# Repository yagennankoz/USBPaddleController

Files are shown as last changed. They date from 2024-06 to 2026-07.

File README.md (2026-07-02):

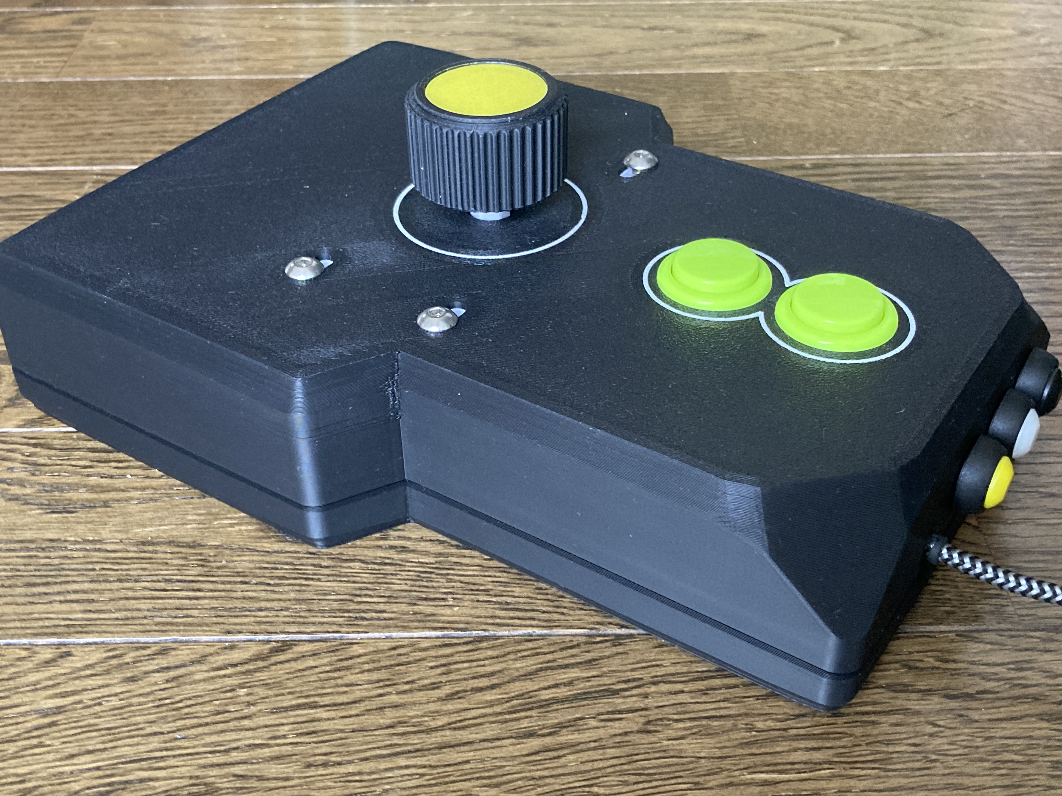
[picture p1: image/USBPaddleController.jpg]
USBパドルコントローラ外観
<br>
RaspberryPi pico版<br>
<br>
USBパドルコントローラ外観<br>
RP2040-Zero版<br>
<br>
<br>

# USBPaddleController

raspberrypi picoを使用したUSBパドルコントローラです<br>
USBマウスとして動作しますので、それらの入力を受け付けるソフトであれば大抵動くんじゃないかと思います *(USBゲームパッドモードも追加しました)*<br>
X/Y軸の切り替えと速度変更にも対応しています<br>

## パドル本体について
パドルユニット部は、ういよめん氏作のパドルコントローラを使用します<br>
https://www.thingiverse.com/thing:5404242
<br>
ういよめん氏のBOOTHで購入する、自分で3Dプリントする等の手段で別途ご用意ください<br>
https://uiyomengames.booth.pm/items/3914858
<br>
当方未確認ですが、ういよめん氏のパドルコントローラのネジ位置はアーケード版アルカノイド用のパドルと寸法が合わせてあるそうなので、そちらも使えるかもしれません<br>

## パドル以外のハードウェア
hardwareフォルダにはパドルユニットに組み付けるセンサー基板とpicoを載せるメイン基板の回路図とガーバーを入れておきました<br>
ガーバーのzipファイルをそのままJLCPCBに送ることで基板を発注できます(たぶん数百円)<br>
組立時の注意としては、センサー基板は位置がずれると正常に動きを検知できなくなるようです<br>
パドルユニットの「ギア4」の中心が二つのセンサーの中心付近にくるようにしてください<br>

## 使用部品

### メイン基板 (RaspberryPi pico版)
| 部品 | 型番 | 個数 | 備考 |
| --- | --- | --- | --- |
| マイコン | RaspberryPi pico | 1 | |
| ダイオード | 1SS178 | 2 | メイン基板 D1,D2 |
| XHコネクタ ベース付ポスト トップ型 2P | B2B-XH-A(LF)(SN) | 5 | メイン基板J2-J6 |
| XHコネクタ ベース付ポスト トップ型 4P | B4B-XH-A(LF)(SN) | 1 | メイン基板J1 |

<br>
<br>

### メイン基板 (RP2040-Zero版)
| 部品 | 型番 | 個数 | 備考 |
| --- | --- | --- | --- |
| マイコン | RP2040-Zero | 1 | |
| ダイオード | 1SS178 | 2 | メイン基板 D1,D2 |
| XHコネクタ ベース付ポスト トップ型 2P | B2B-XH-A(LF)(SN) | 5 | メイン基板J2-J6 |
| XHコネクタ ベース付ポスト トップ型 4P | B4B-XH-A(LF)(SN) | 1 | メイン基板J1 |

<br>
<br>

### センサー基板 (センサー基板はpico/RS2040-Zero共通です)
| 部品 | 型番 | 個数 | 備考 |
| --- | --- | --- | --- |
| インバータ | 74HC14<br>(U74HC14L-D14-T) | 1 | センサー基板 |
| 透過型フォトインタラプタ | SG206 | 2 | センサー基板 U2,U3 他のパーツの裏側に付きます |
| カーボン抵抗 | 180Ω | 2 | センサー基板 R1,R2 |
| カーボン抵抗 | 2.2kΩ | 2 | センサー基板 R3,R4 |
| XHコネクタ ベース付ポスト トップ型 4P | B4B-XH-A(LF)(SN) | 1 | センサー基板J1|

<br>
<br>

### 配線 (pico/RS2040-Zero共通)
| 部品 | 型番 | 個数 | 備考 |
| --- | --- | --- | --- |
| XHコネクタ ハウジング 2P | XHP-2 | 5 | |
| XHコネクタ ハウジング 4P | XHP-4 | 2 | |
| XHコネクター ハウジング用コンタクト | SXH-001T-P0.6 | 18 |  |
| 配線 | | 適量 | 最低4色は揃えるのが良いでしょう |

<br>
<br>

### ケース(RaspberryPi pico版)
| 部品 | 型番 | 個数 | 備考 |
| --- | --- | --- | --- |
| 24φネジ式押しボタン | PS-14-DN | 2 | |
| ネジ径12Φ押しボタン |  | 3 | |
| M3 インサートナット |  | 6 | ケース上部パーツの穴に入れる |
| M3 5mm ビス |  | 4 | |
| M5 ナット |  | 4 | パドルユニットをケースに組み付けるのに使用 |
| M5 15mm ビス |  | 4 | パドルユニットをケースに組み付けるのに使用 |
| M3 6mm タッピングビス |  | 6 | ケースにメイン基板を固定するのに4個<br>パドルユニットにセンサー基板を固定するのに2個 |

<br>
<br>

### ケース(RS2040-Zero版)
| 部品 | 型番 | 個数 | 備考 |
| --- | --- | --- | --- |
| 24φネジ式押しボタン | PS-14-DN | 3 | |
| サービススイッチ(DS-412) |  | 2 | |
| M3 インサートナット |  | 7 | ケース上部パーツの穴に入れる |
| M3 5mm ビス |  | 4 | |
| M5 ナット |  | 4 | パドルユニットをケースに組み付けるのに使用 |
| M5 15mm ビス |  | 4 | パドルユニットをケースに組み付けるのに使用 |
| M3 6mm タッピングビス |  | 3 | ケースにメイン基板を固定するのに3個<br>パドルユニットにセンサー基板を固定するのに2個<br> |

<br>
<br>

### パームレスト(RS2040-Zeroケース用追加装備)
| 部品 | 型番 | 個数 | 備考 |
| --- | --- | --- | --- |
| M3 8mm ビス |  | 2 | |

<br>
<br>

### メイン基板上のコネクタとスイッチの対応
| picoコネクタ# | RP2040-Zeroコネクタ# | スイッチ# | 機能 |
| --- | --- | --- | --- |
| J2 | J2 | SW1 | 左ボタン |
| J3 | J3 | SW2 | 右ボタン |
| J4 | J5 | SW3 | 速度切り替えボタン |
| J5 | J6 | SW4 | X/Y軸切り替えボタン |
| J6 | J4 | SW5 | センターボタン |

<br>
<br>
<br>

## ファームウェアの書込み

### RaspberryPi picoの場合
picoのBOOTSELを押しながらUSBケーブルを接続するとエクスプローラーが起ち上がり、picoのフォルダが表示されます(winの場合）<br>
そこにUSBPaddleController_pico.uf2をコピーしてください<br>
ファームウェアの更新が完了するとpicoが再起動します<br>

### RP2040-Zeroの場合
PCに接続した状態でZeroのBOOTを押しながらRESETを押下するとエクスプローラーが起ち上がり、Zeroのフォルダが表示されます(winの場合）<br>
そこにUSBPaddleController_rp2040_zero.uf2をコピーしてください<br>
ファームウェアの更新が完了するとZeroが再起動します<br>
<br>
<br>
<br>

## ボタンの機能について
### 速度切り替えボタン
SW3は速度切り替えボタンです<br>
パドルの反応速度を4段階で切り替えることが可能です<br>
押下するごとに高速から順に低速に切り替わり、最低速の次は高速に戻ります<br>
切り替え後の速度はLEDのフラッシュで通知されます(最高速=1回...最低速=4回)<br>

### X/Y軸切り替えボタン
SW4はX/Y軸切り替えボタンです<br>
押下するごとにマウスの移動方向が切り替わります<br>
X軸移動のみでは「メタルオレンジEX」のメニュー操作ができなかったので追加しました<br>
*軸切り替えボタンと右または左ボタン同時押しのセンタークリックは廃止しました*<br>

### 連射モード
**速度切替ボタンを押しながら**左右センターいずれかのボタンを押すと連射モードのON/OFF切り替えが行われます<br>
連射モードONになっているボタンを押下している間、連射します<br>
連射速度は秒間10発程度の固定です<br>

---

### ゲームパッドモード(ポールポジションモード)
**X/Y軸切り替えボタン**と**速度切り替えボタン**を同時押しすると、USBマウスモードとUSBゲームパッドモードが交互に切り替わります<br>
ゲームパッドモードに切り替わった時、LEDが10秒間点滅します(RP2040-Zetoでは緑色点滅)<br>
マウスモードに切り替わった時、LEDが10秒間点灯します(RP2040-Zetoでは赤色点灯)<br>
USBゲームパットモードではボタンの機能が以下のようになります<br>

| マウス操作 | パッド操作 |
| --- | --- |
| 回転 | 左スティック |
| 左 | R2<br>3秒以上長押しした後に離すと、L2が自動で0.9秒間連打されます(オートブレーキ)<br>L2連打中に再度ボタン押下で連打がキャンセルされます<br>オートブレーキ作動中はLEDが点滅します |
| 右 | ×/□のトグル動作 |
| センター | △ |
| 速度切り替え | PS |

速度切り替え/連射は無効化されます<br>
その他のボタン機能はUSBマウスモードと同様に機能します<br>
PS5との接続はFGC2を介してどうにかなるかもしれません<br>

---

### 設定の保存
マウス/ゲームパッドのモードと各設定値は設定変更のタイミングで保存され、再起動時は設定内容を復元します<br>
設定値はマウス/ゲームパッドのモード毎に保存されます<br>
<br>
<br>

---

### ケースについて
パドルコントローラのケースはサイズ違いのものを用意しました<br>
小さい方は20cmX20cmのヒートベッドで出力可能ですが、2ボタン仕様であり手の置き場もないため若干操作しづらくなっています<br>
大きい方はケースの締め付けにインサートナットを使用しますので別途ご用意ください<br>
自作されたり、アーケード機のコントロールボックス等に入れるのも良いと思います<br>
<br>

---

### 組み立て手順
#### パドルユニットの作成
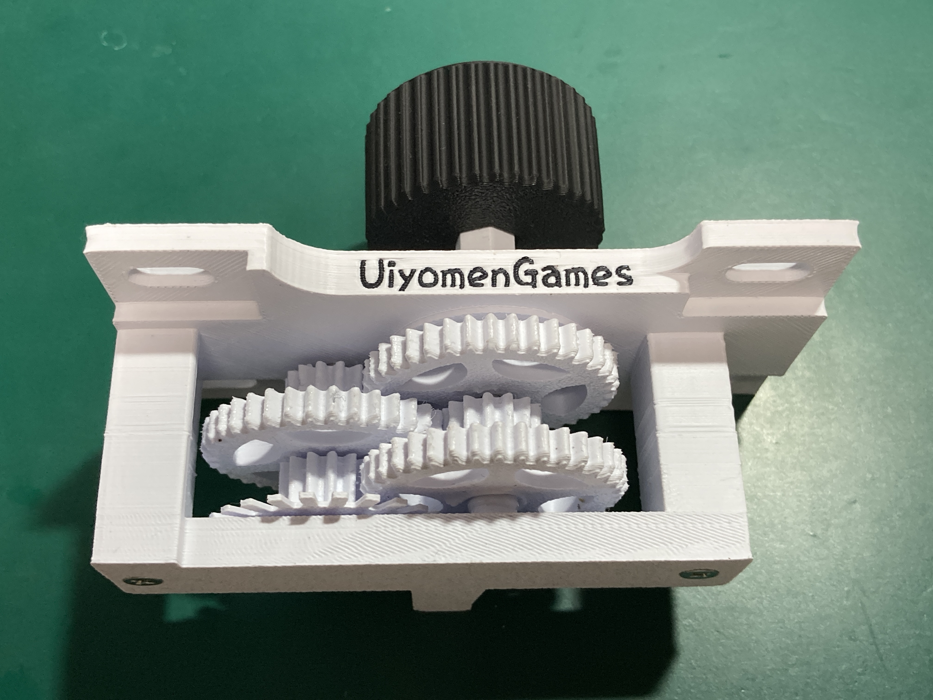
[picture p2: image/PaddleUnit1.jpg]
パドルユニット
<br>
<br>

- 公開されているデータをもとに3Dプリント等を行ってください<br>
<br>

***
#### 基板の作成
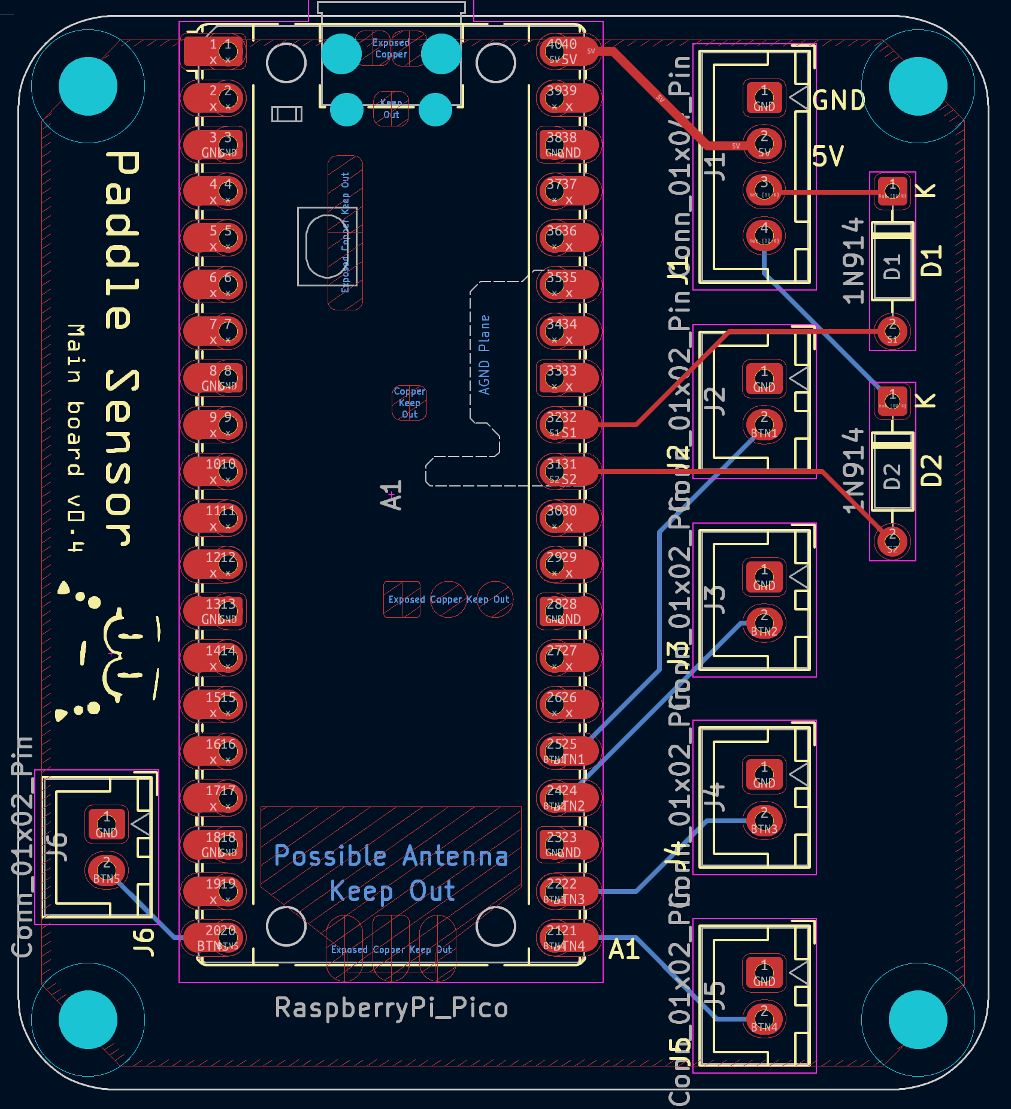
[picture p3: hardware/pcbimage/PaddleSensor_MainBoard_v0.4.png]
メイン基板 pico用
<br>
メイン基板 RaspberryPi pico用<br>
<br>
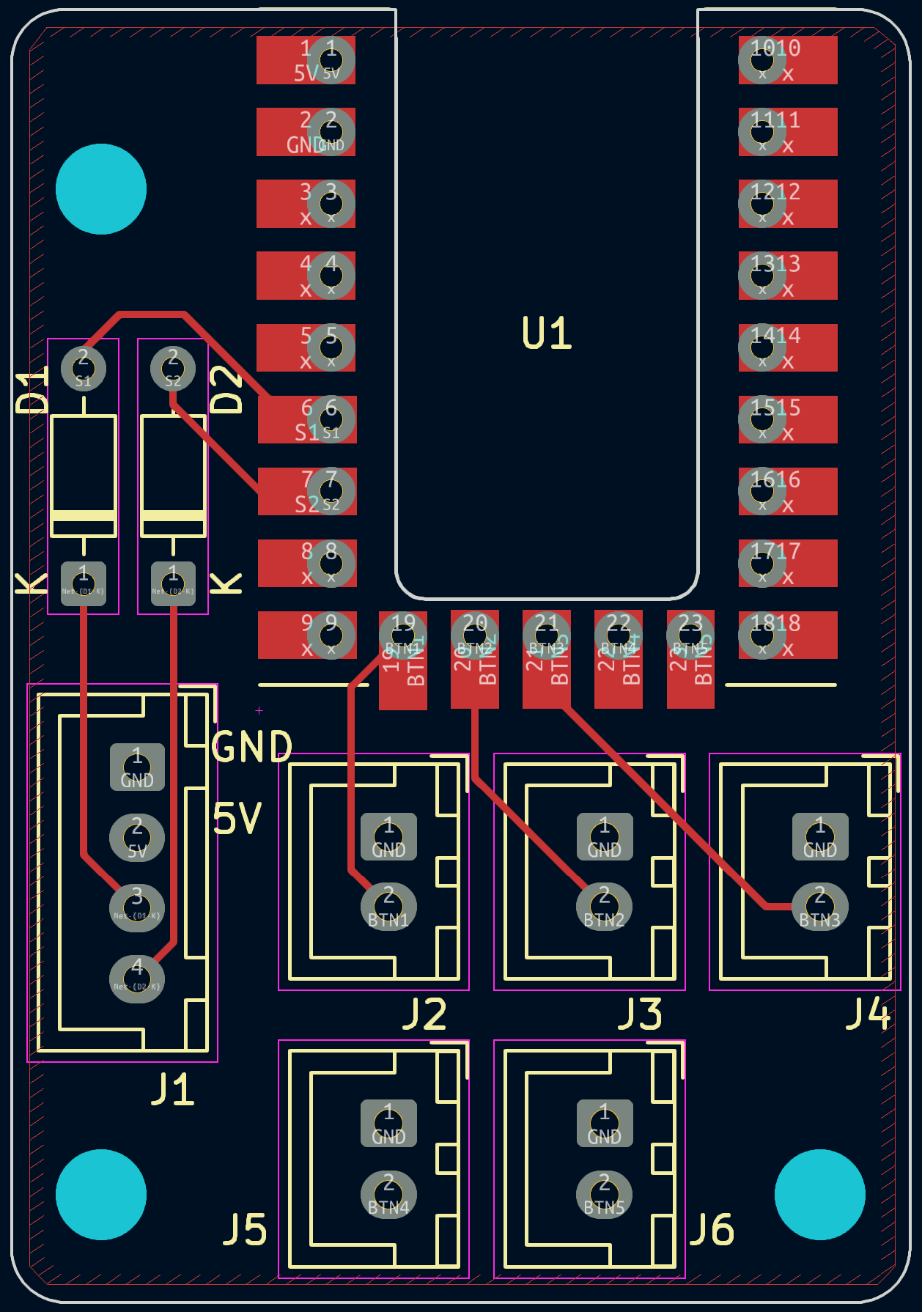
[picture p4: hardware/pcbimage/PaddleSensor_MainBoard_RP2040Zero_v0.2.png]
メイン基板 RP2040-Zero用
<br>
メイン基板 RP2040-Zero用<br>
<br>
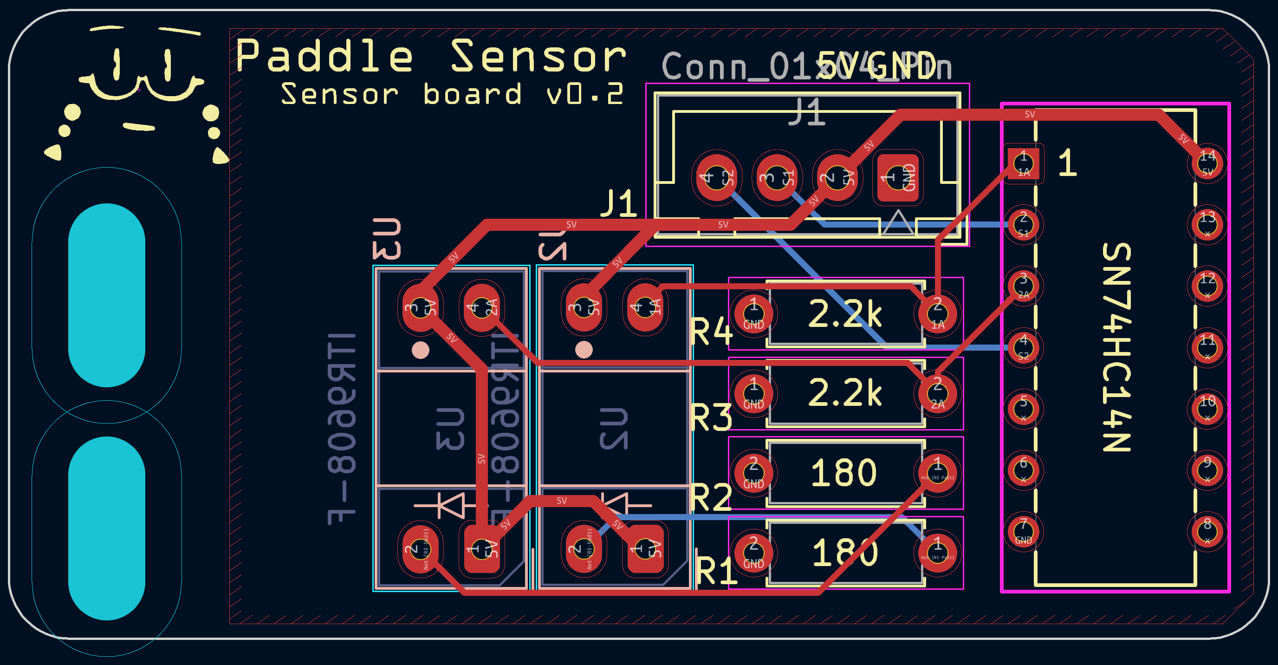
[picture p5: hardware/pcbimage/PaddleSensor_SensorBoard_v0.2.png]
センサー基板
<br>
センサー基板<br>
<br>
<br>

- 基板イメージと使用部品表を参考に部品を半田付けしてください<br>
- メイン基板は使用するマイコンによってRaspberryPi pico用かRP2040-Zero用のどちらかを使用してください<br>
- センサー基板はどちらのマイコンを使う場合でも共通です<br>
- メイン基板へのRaspberryPi picoの取り付けはピンヘッダ／ソケットを使用することを前提としています<br>
- メイン基板へのRP2040-Zeroの取り付けはピンヘッダを使用せず直接はんだ付けすることを前提としています<br>
- センサー基板のフォトインタラプタはその他の部品の裏側の面に実装します<br>
<br>

***
#### パドルユニットにセンサー基板を取り付け
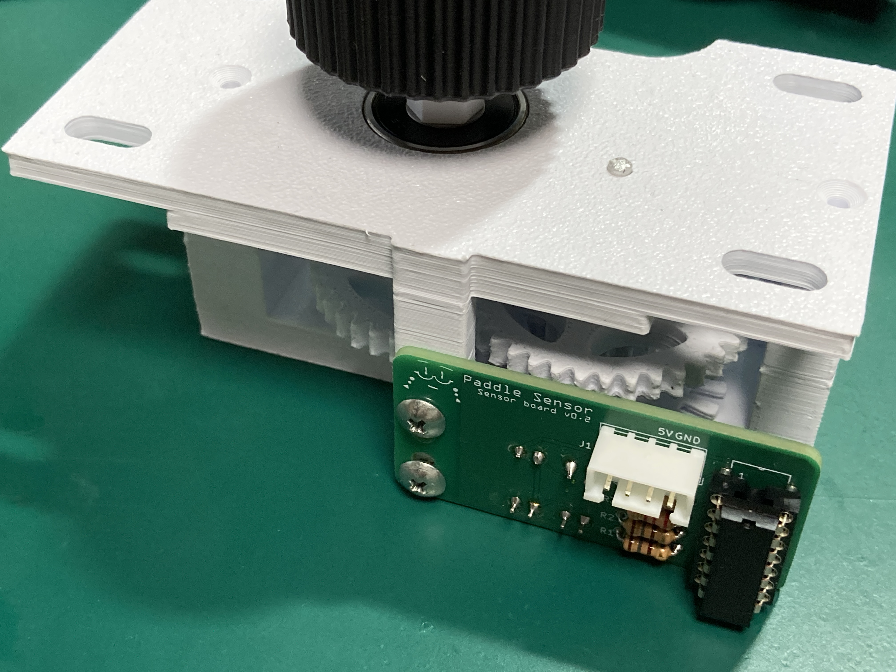
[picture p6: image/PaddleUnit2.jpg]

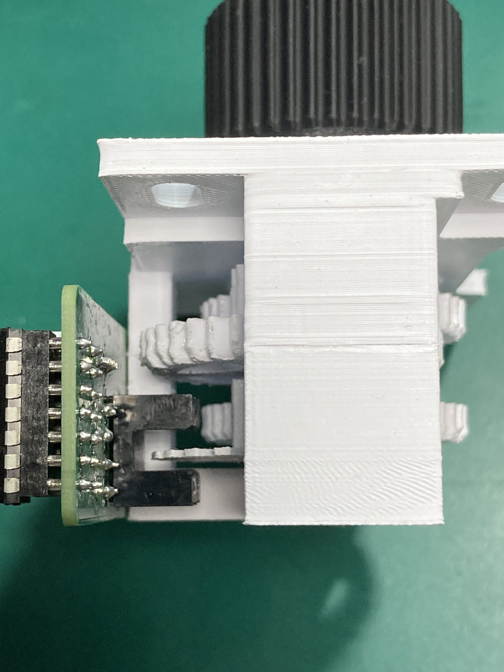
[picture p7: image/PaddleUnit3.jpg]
<br>
<br>

- パドルユニットにセンサー基板を取り付けます<br>
- フォトインタラプタとパドルユニットの円盤が接触しないようにしてください<br>
<br>

***
#### ケース(上)にインサートナットの埋め込み
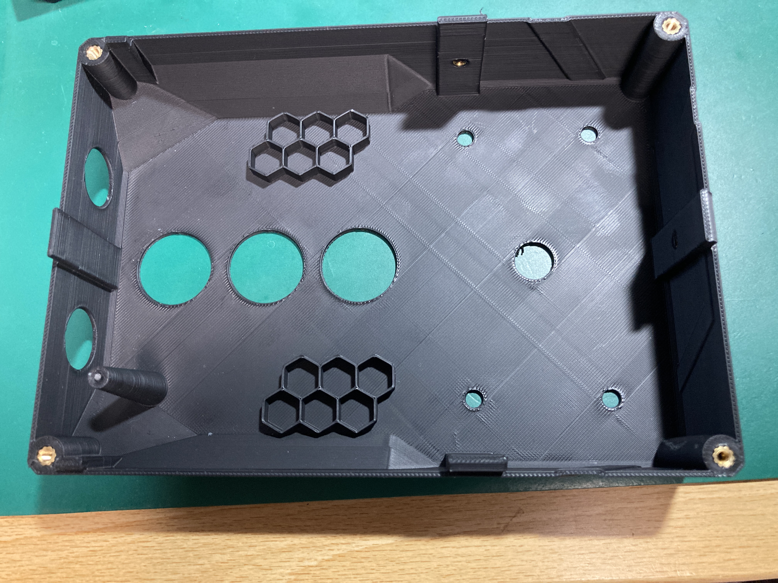
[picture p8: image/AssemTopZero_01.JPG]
<br>

- ケース(上)の底面の穴にM3用のインサートナットを埋め込みます
- pico用は6か所、RP2040-Zero用は4か所です

<br>
<br>
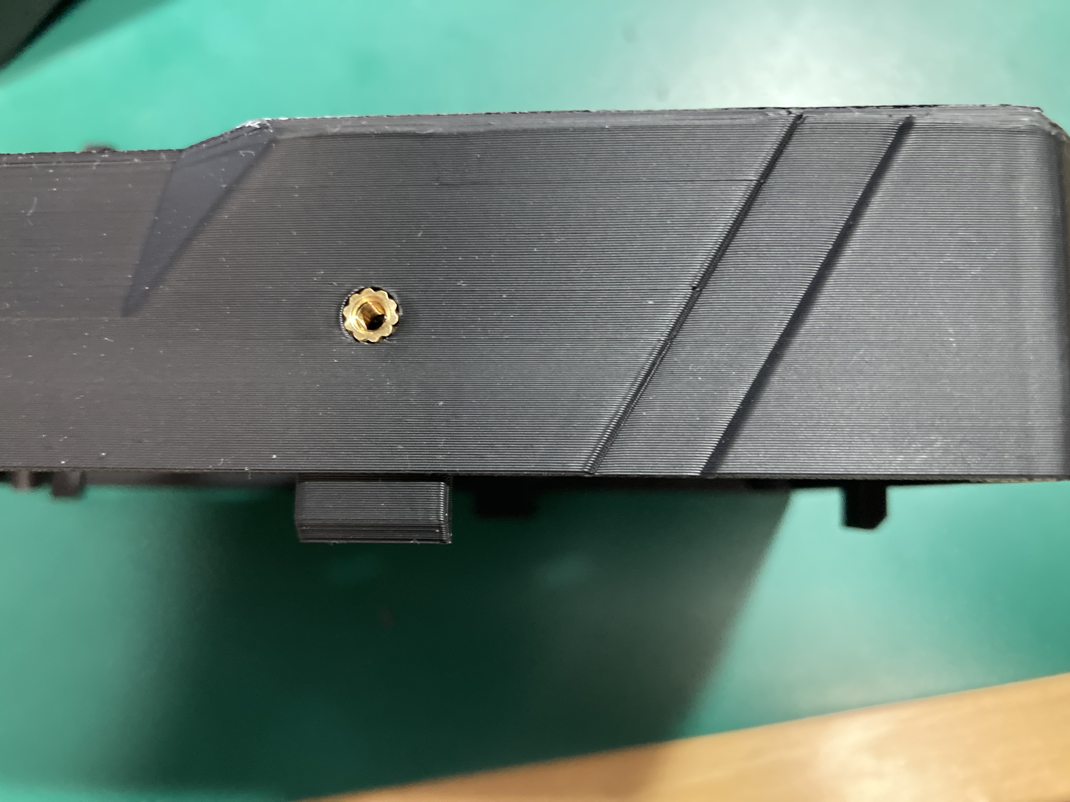
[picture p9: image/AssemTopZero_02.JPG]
<br>

- RP2040-Zero用は側面の3か所の穴にもM3用のインサートナットを埋め込みます

<br>
<br>

***
#### ケース(上)に透明フィラメントの埋め込み(RP2040-Zeroのみ)
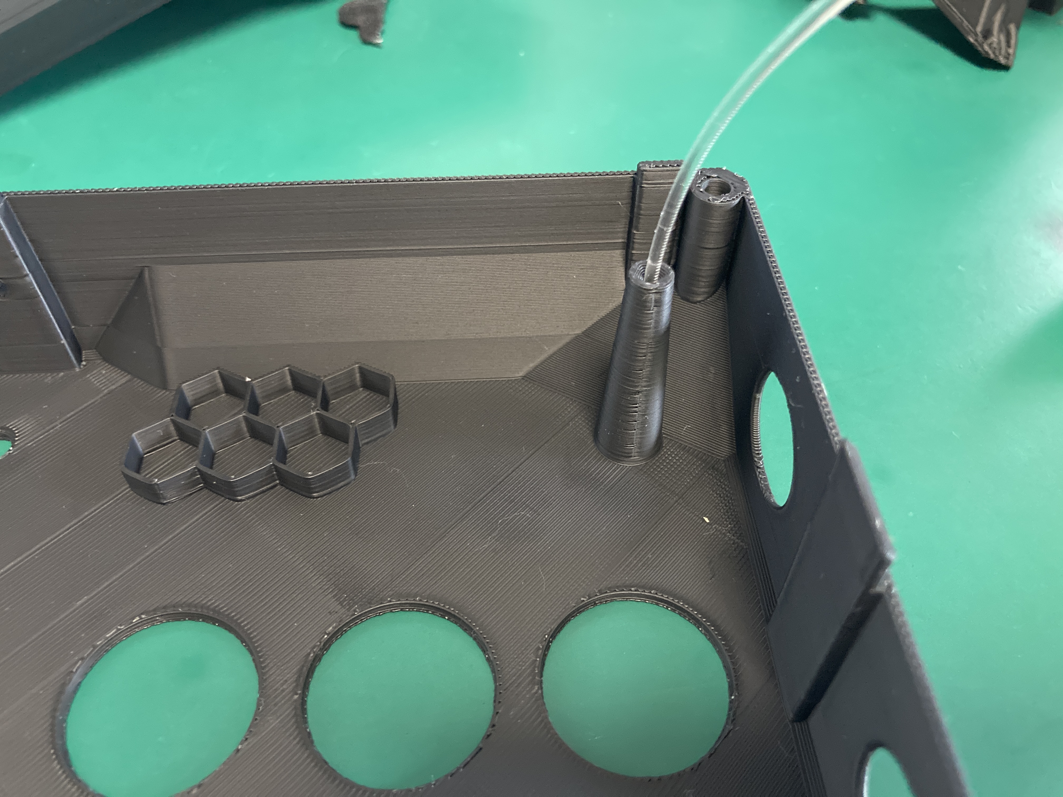
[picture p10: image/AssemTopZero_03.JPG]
<br>
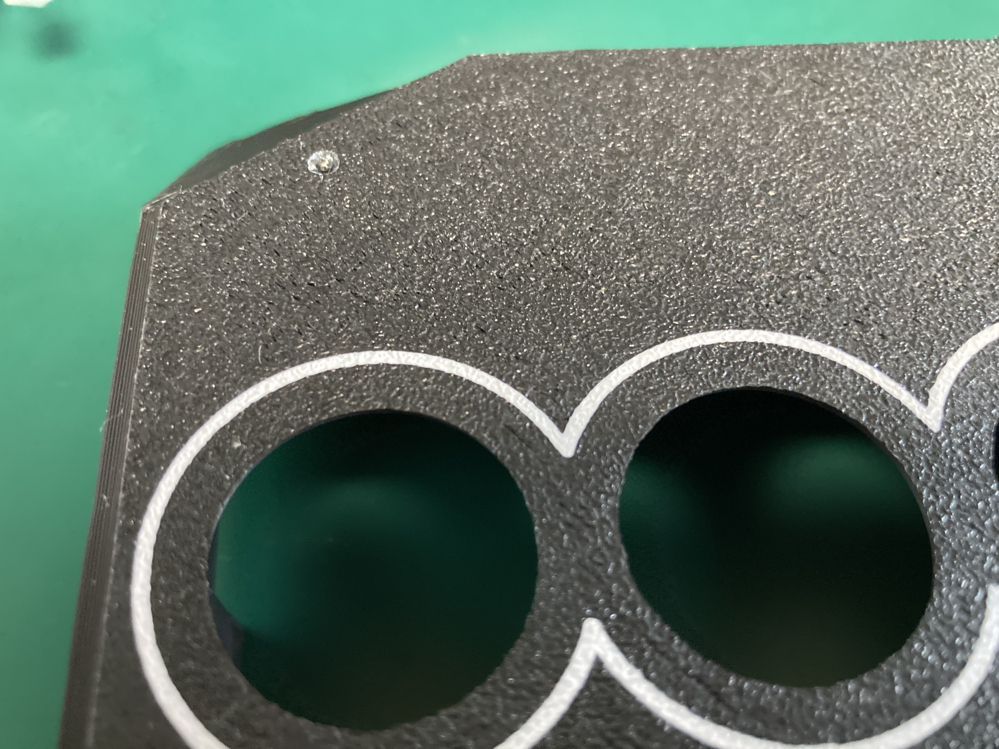
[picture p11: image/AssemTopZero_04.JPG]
<br>
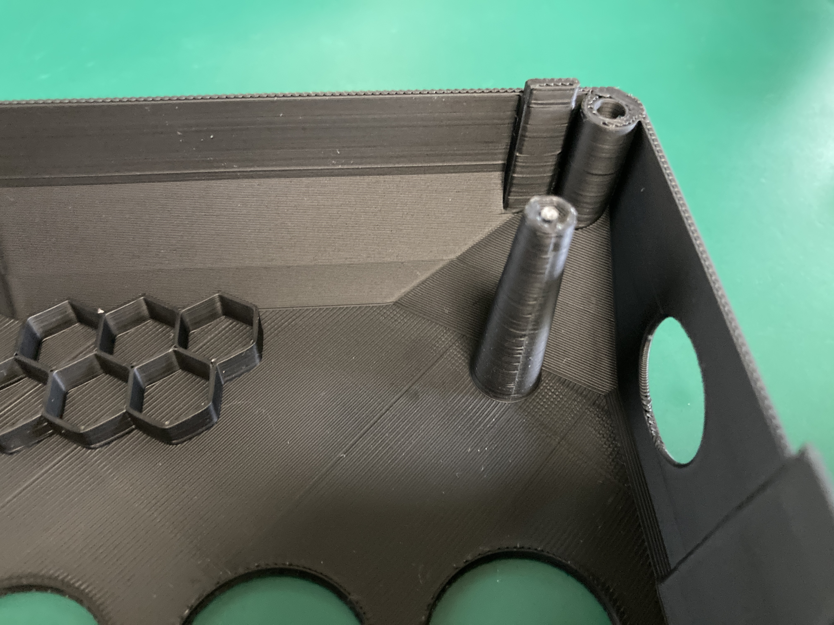
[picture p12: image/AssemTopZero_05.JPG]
<br>

- 2mm穴に透明フィラメントを埋め込みます
- 両端がケースの面とツライチになるようにカットしてください
- 透明フィラメントが無い場合はスキップしても問題ありません

<br>
<br>

***
#### ケース(上)にパドルユニットとスイッチを取り付け
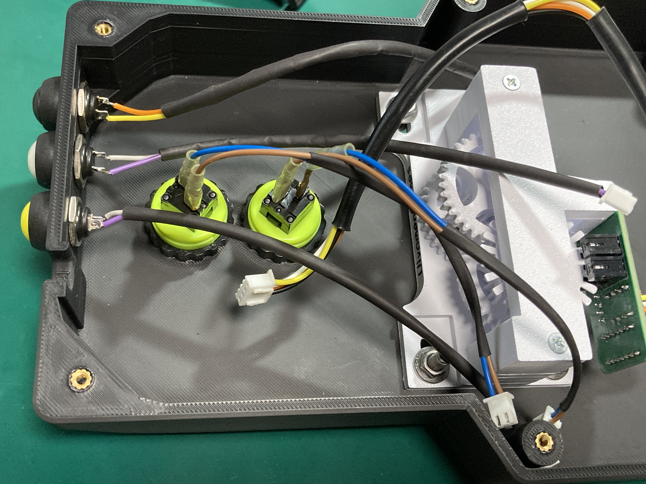
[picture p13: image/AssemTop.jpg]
picoケース(上)
<br>
<br>
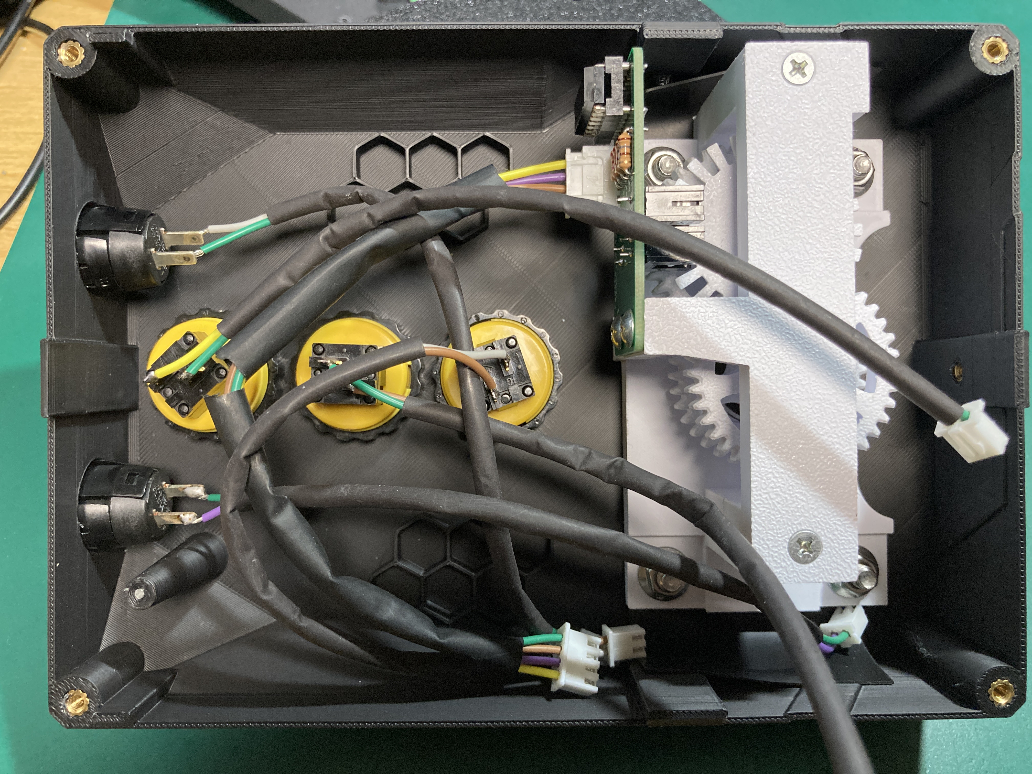
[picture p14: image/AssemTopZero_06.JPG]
Zeroケース(上)
<br>
<br>

- ケース(上)にパドルユニットとボタンを取り付けます
- pico用とRP2040-Zero用ではパドルユニットが異なっています

<br>
<br>

***
#### ケース(下)にメイン基板を取り付け
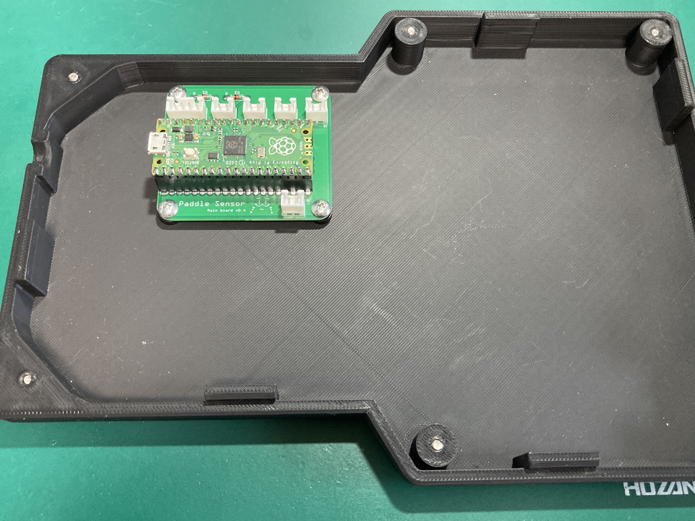
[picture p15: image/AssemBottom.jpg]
ケース(下)
<br>
<br>

- ケース(下)にメイン基板を取り付けます<br>

***
#### メイン基板と接続
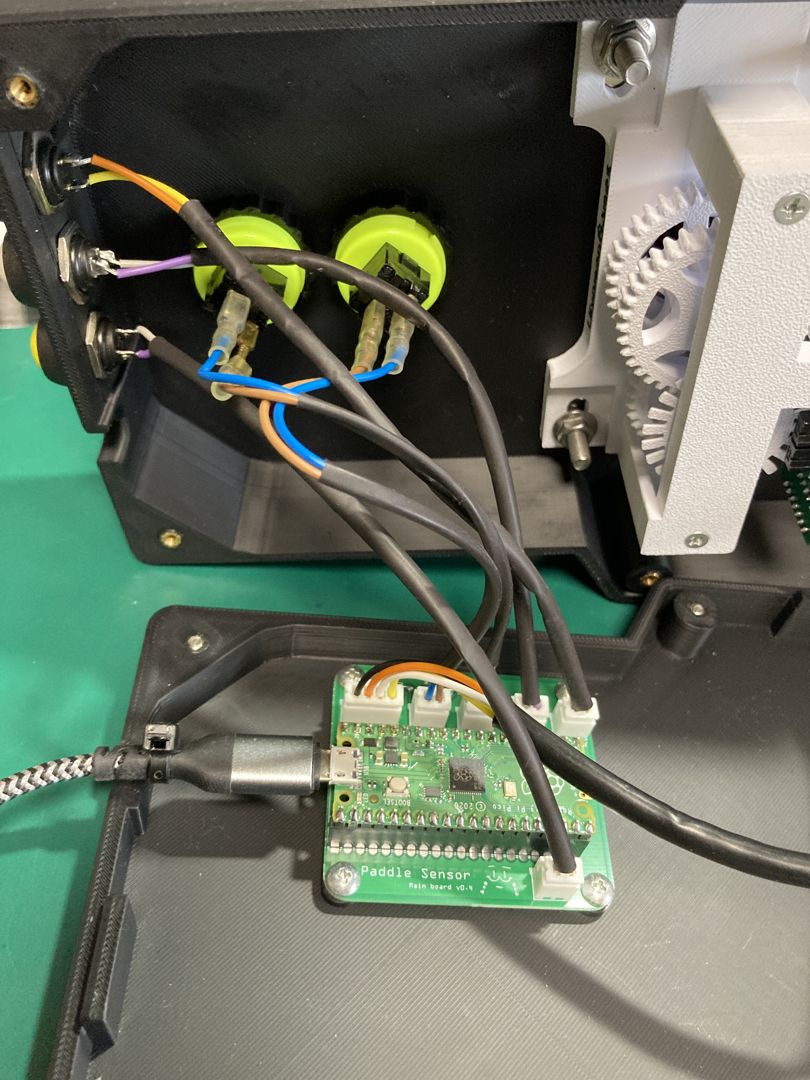
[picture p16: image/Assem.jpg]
配線
<br>
<br>

- メイン基板とセンサー基板、各スイッチを接続します<br>
- スイッチ類はすべて同じコネクタ形状ですので、配置はお好みで組み替えてください<br>

***
#### 完成
完成<br>
<br>
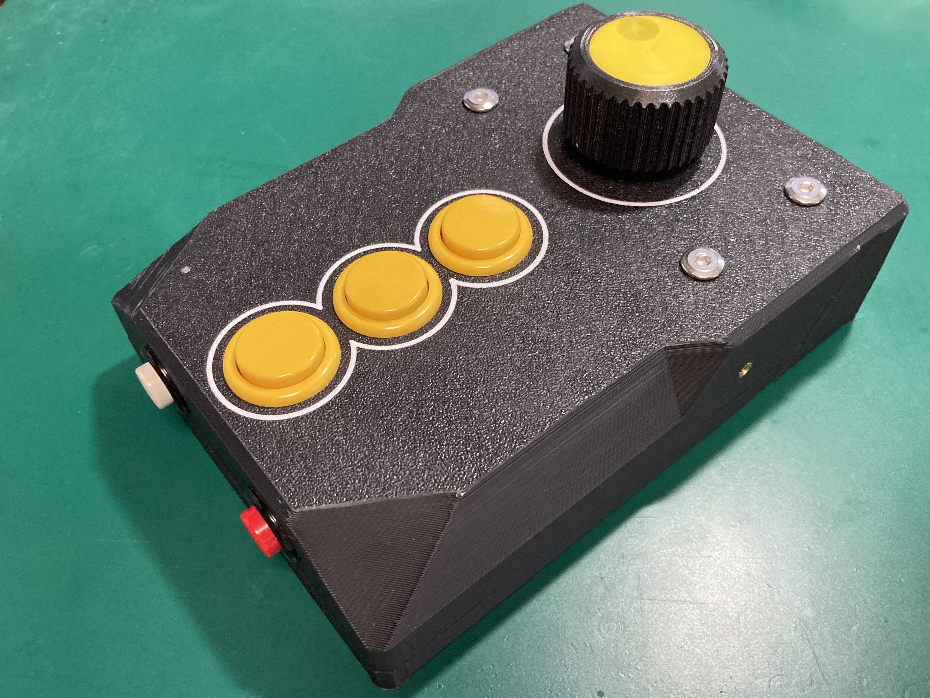
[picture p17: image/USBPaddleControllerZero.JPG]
<br>
<br>

- ケースを閉じて完成です　お疲れさまでした<br>
<br>
<br>

---
### RP2040-Zero用追加装備
RP2040-Zero用ケースは側面に3か所のナットが埋め込まれています<br>
ここに追加装備を装着することが可能です<br>
<br>

#### パームレスト
RP2040-Zero用ケースはコンパクトになった反面、手を置くスペースがなくなっているので、外付けのパームレストを作成しました<br>
取り付け位置を替えることで右手／左手のどちらにも対応可能です<br>
またパームレスト天面にM3ビス用の穴を5個あけていますので、上部にさらに装備追加可能です<br>
<br>
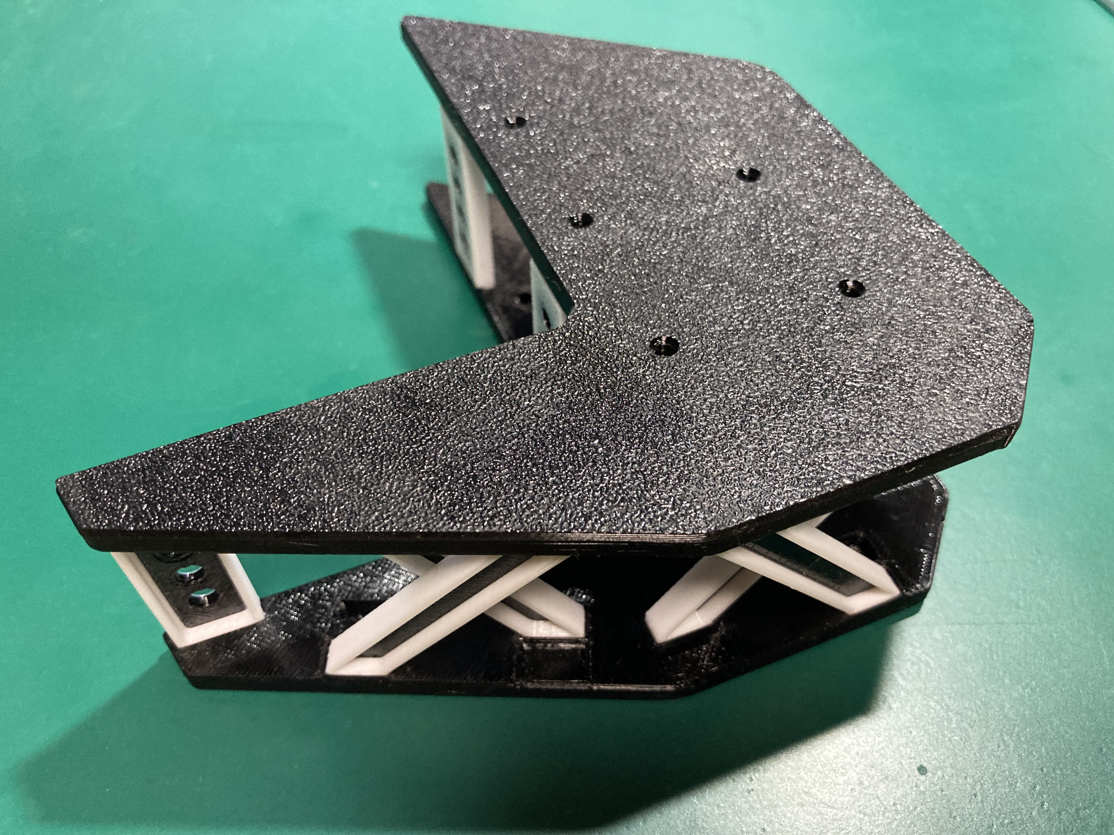
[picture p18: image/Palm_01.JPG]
パームレスト
<br>
パームレスト<br>
パームレスト<br>

<br>
<br>

#### パームレスト組立手順
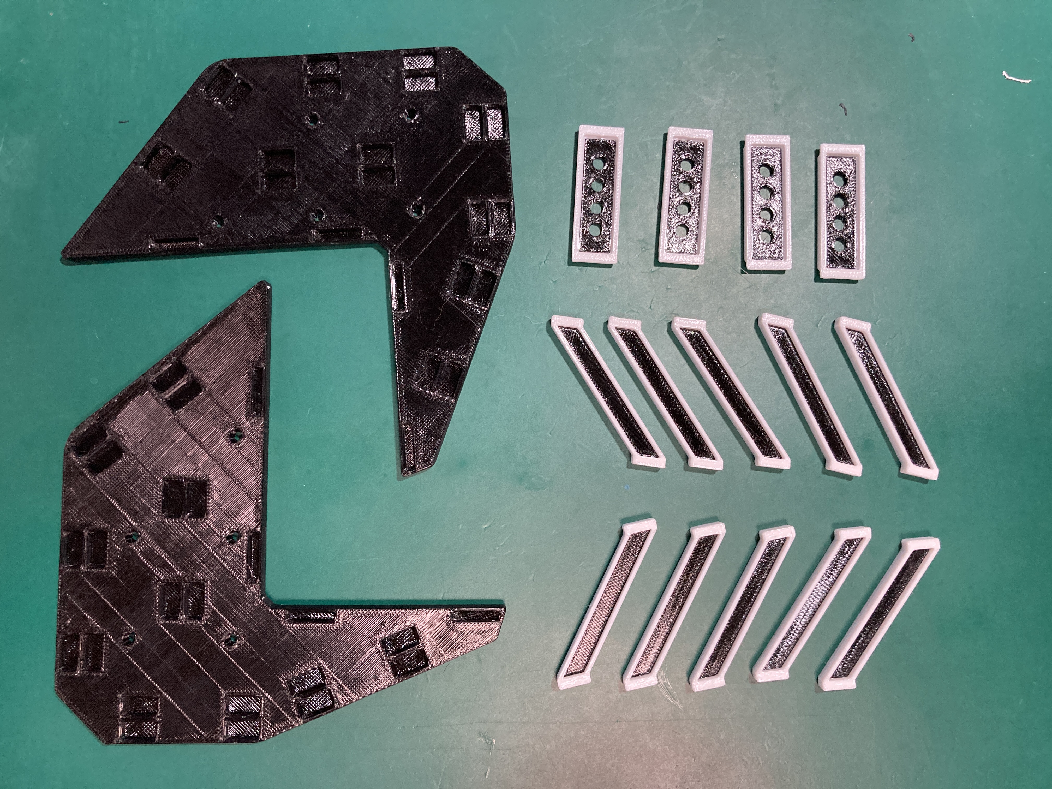
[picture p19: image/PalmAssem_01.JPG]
パームレスト部品
<br>
<br>
- 部品を準備します
- 垂直支柱は4本、斜め支柱は2種類を各5本ずつ出力してください

<br>

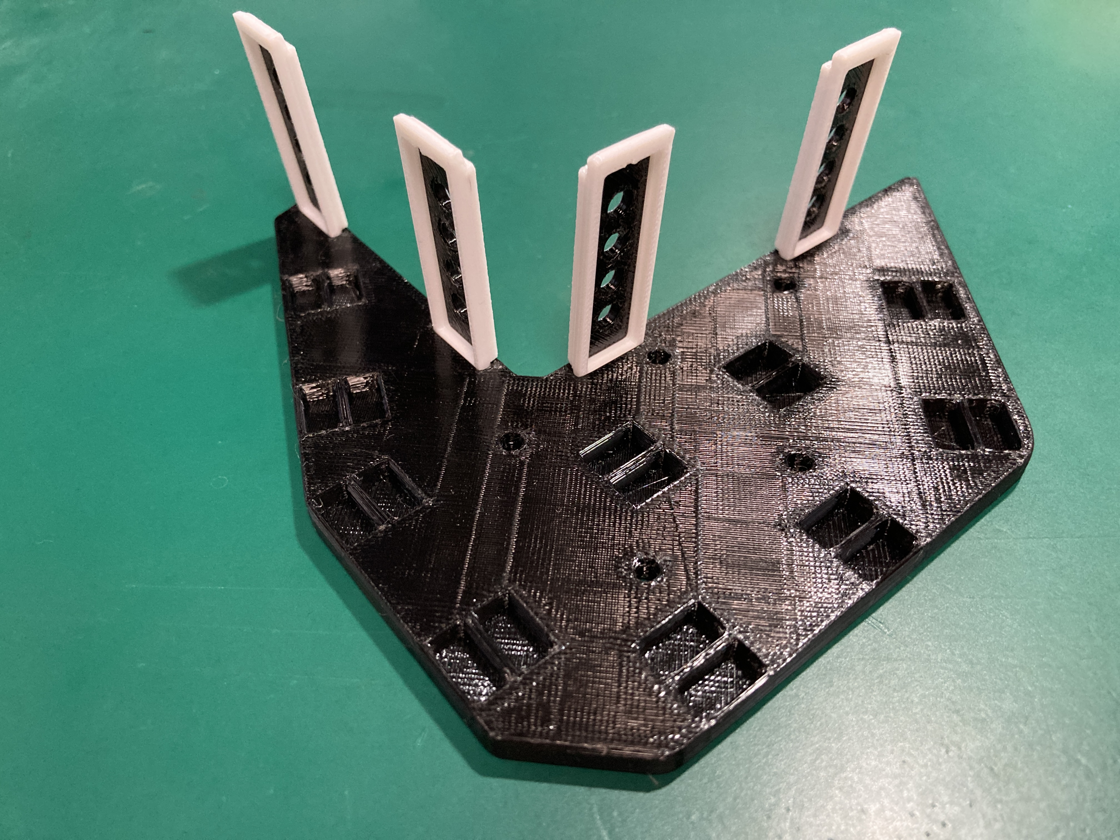
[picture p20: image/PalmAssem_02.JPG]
<br>
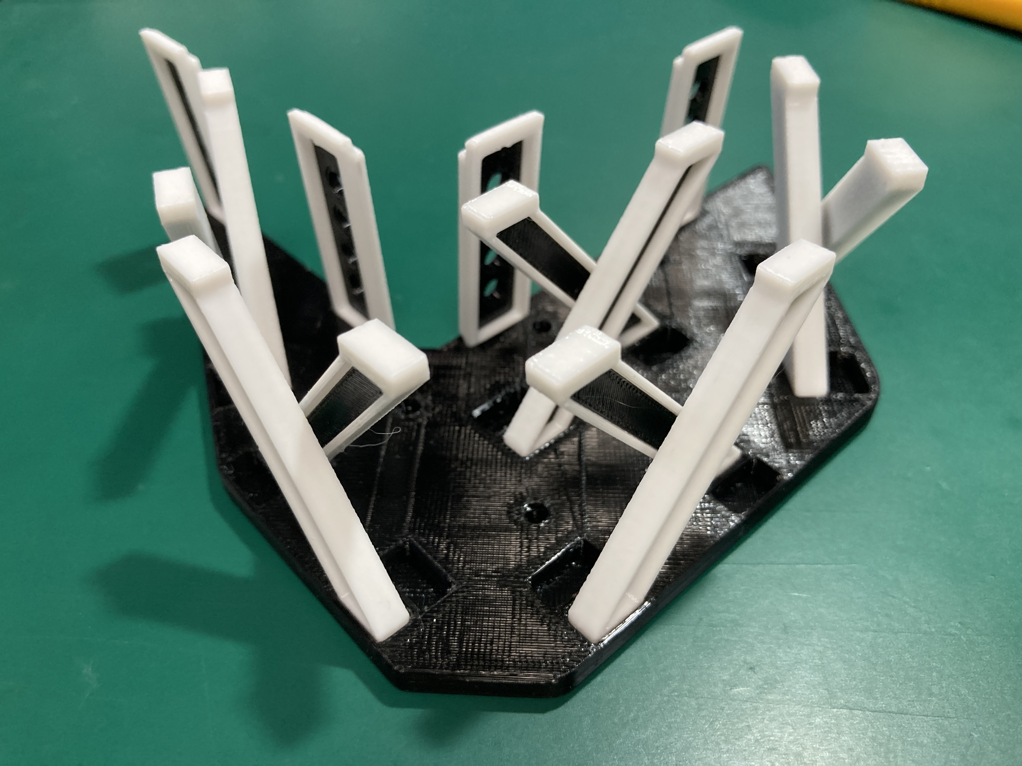
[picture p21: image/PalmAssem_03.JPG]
<br>
<br>
- 片方のプレートに支柱を立てます
- 垂直支柱は窪みがある面を斜め支柱が刺さる穴の方に向けてください
- 斜め支柱の向きや本数はお好みでどうぞ

<br>

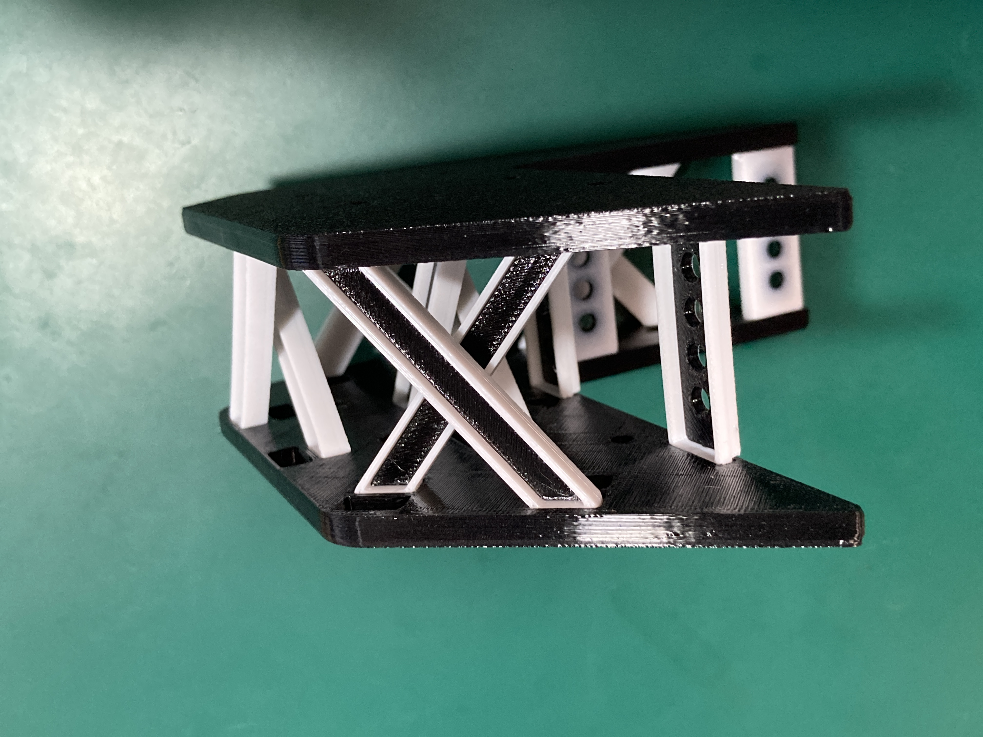
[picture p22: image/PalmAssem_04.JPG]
<br>
<br>
- もう片方のプレートに立てている支柱を差し込んで完成です

<br>
<br>

---
### テスト環境
以下のテスト環境で動作確認を行っています<br>
- X68000 Z<br>
- PlayStation 5 (ゲームパッドモードはBrook FGC2を使用)<br>
- Windows11<br>
<br>

---

### 参考サイト
- ういよめん氏　Arkanoid Paddle (spinner) controller Rotary encoder<br>
https://www.thingiverse.com/thing:5404242

- わいくん氏　ゲーム基板用センサー図鑑<br>
https://www.ykuns-mechanical-club.com/game%20sensor.html

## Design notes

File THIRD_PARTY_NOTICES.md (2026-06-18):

# THIRD-PARTY NOTICES

This repository uses third-party software components.

Generated: 2026-06-18

## Scope

- This file documents licenses for components resolved by PlatformIO for environment `pico`.
- Actual linked components can vary by platform/core/library versions.
- This file is for notice purposes only and is not legal advice.

## Direct Dependency (declared in platformio.ini)

### Adafruit TinyUSB Library

- Name: Adafruit TinyUSB Library
- Version observed: 2.4.1
- Declared constraint: `adafruit/Adafruit TinyUSB Library@^2.3.1`
- License: MIT
- Upstream: https://github.com/adafruit/Adafruit_TinyUSB_Arduino
- Local evidence:
  - `.pio/libdeps/pico/Adafruit TinyUSB Library/LICENSE`
  - `.pio/libdeps/pico/Adafruit TinyUSB Library/library.properties`

## Dependencies Observed In Build Graph

The following were present in the PlatformIO dependency graph during build:

- Adafruit TinyUSB Library @ 2.4.1
- EEPROM @ 1.0 (framework-provided)
- SPI @ 1.0 (framework-provided)

Framework package in use:

### framework-arduinopico

- Name: Arduino-Pico core package (`framework-arduinopico`)
- Version observed: 1.30601.0+sha.c3a3526
- License file indicates: GNU Lesser General Public License v2.1 (LGPL-2.1)
- Upstream: https://github.com/earlephilhower/arduino-pico
- Local evidence:
  - `C:/Users/hasegawa/.platformio/packages/framework-arduinopico/LICENSE`

## Transitive Dependencies Pulled By Adafruit TinyUSB Library

These were resolved locally as dependencies of Adafruit TinyUSB Library:

### Adafruit SPIFlash

- Version observed: 4.3.4
- License: MIT
- Upstream: https://github.com/adafruit/Adafruit_SPIFlash
- Local evidence:
  - `.pio/libdeps/pico/Adafruit SPIFlash/LICENSE`

### SdFat - Adafruit Fork

- Version observed: 2.2.3
- License: MIT
- Upstream: https://github.com/adafruit/SdFat
- Local evidence:
  - `.pio/libdeps/pico/SdFat - Adafruit Fork/LICENSE.md`
  - `.pio/libdeps/pico/SdFat - Adafruit Fork/library.properties`

## Recommended Distribution Practice

- Keep this notice file with source releases.
- Include each third-party license text when redistributing binaries/source bundles.
- Re-run dependency and license checks when updating PlatformIO platform/core/library versions.

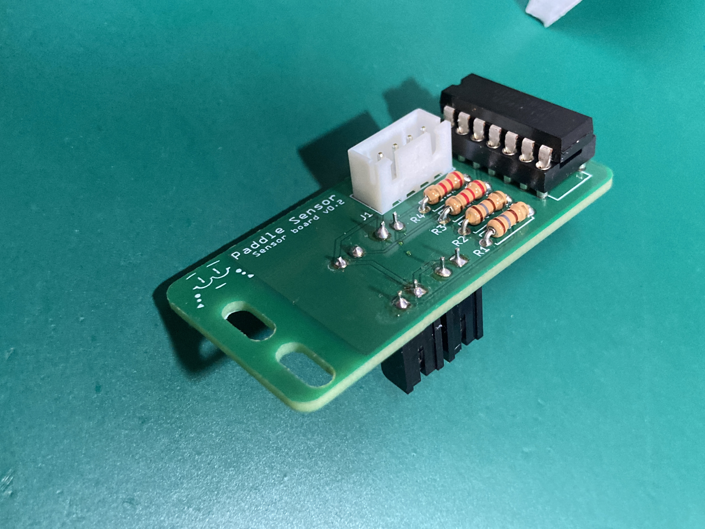
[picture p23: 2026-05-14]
image/SensorBoard.jpg

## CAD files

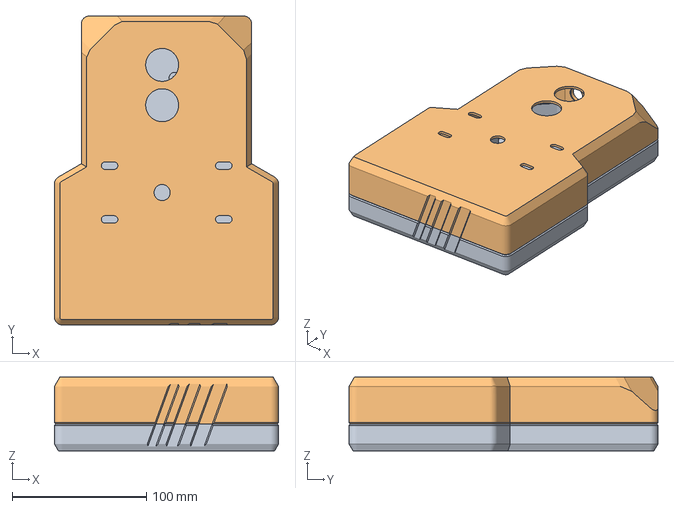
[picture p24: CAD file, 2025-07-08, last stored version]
case/PaddleCaseLarge_4BTN.3mf
166.9 x 230.0 x 55.0 mm
BOTTOM_V2
TOP_V2

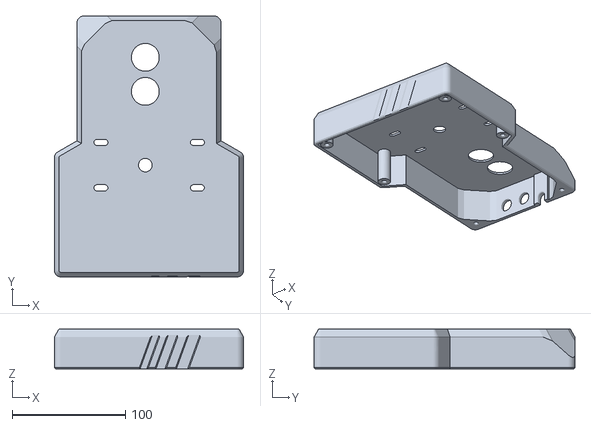
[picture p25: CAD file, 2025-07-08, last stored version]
case/PaddleCaseLarge_TOP_4BTN.stl
166.9 x 230.0 x 35.0

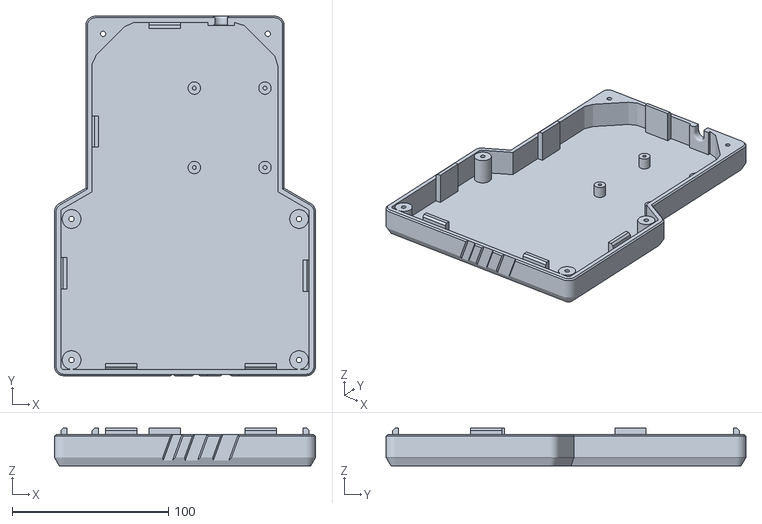
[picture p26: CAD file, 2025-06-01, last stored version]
case/PaddleCaseLarge_BOTTOM.stl
166.9 x 230.0 x 24.0

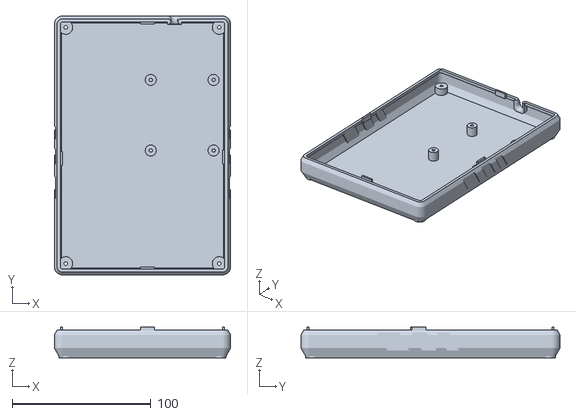
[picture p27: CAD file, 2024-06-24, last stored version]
case/PaddleCase_BOTTOM.stl
126.9 x 186.4 x 22.0

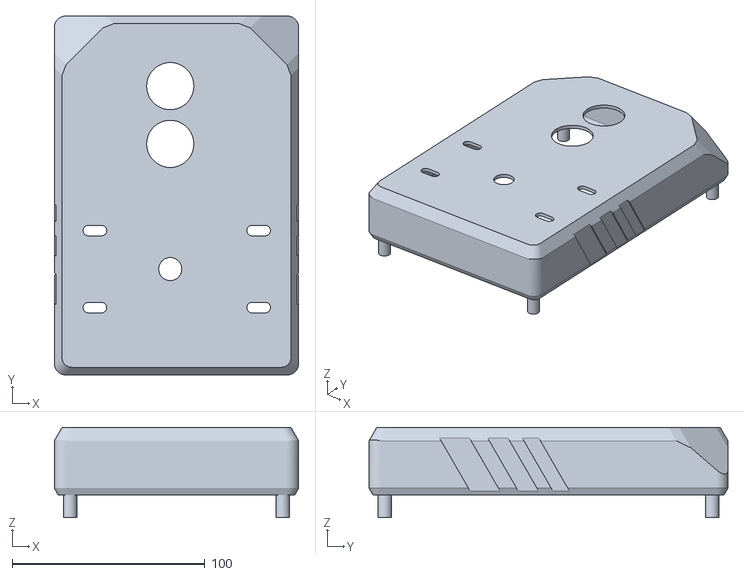
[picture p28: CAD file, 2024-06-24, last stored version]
case/PaddleCase_TOP.stl
126.9 x 186.4 x 46.8

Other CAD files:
case/PaddleCaseLarge.3mf
case/PaddleCaseLarge_TOP.stl

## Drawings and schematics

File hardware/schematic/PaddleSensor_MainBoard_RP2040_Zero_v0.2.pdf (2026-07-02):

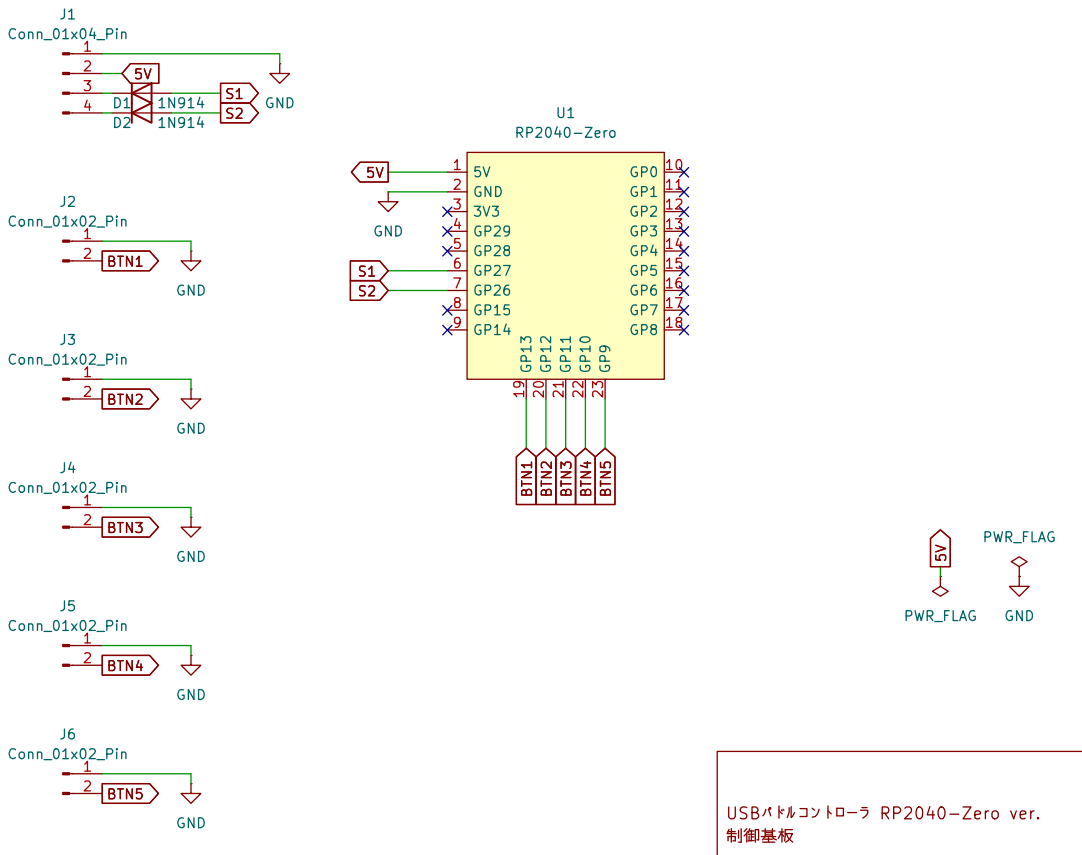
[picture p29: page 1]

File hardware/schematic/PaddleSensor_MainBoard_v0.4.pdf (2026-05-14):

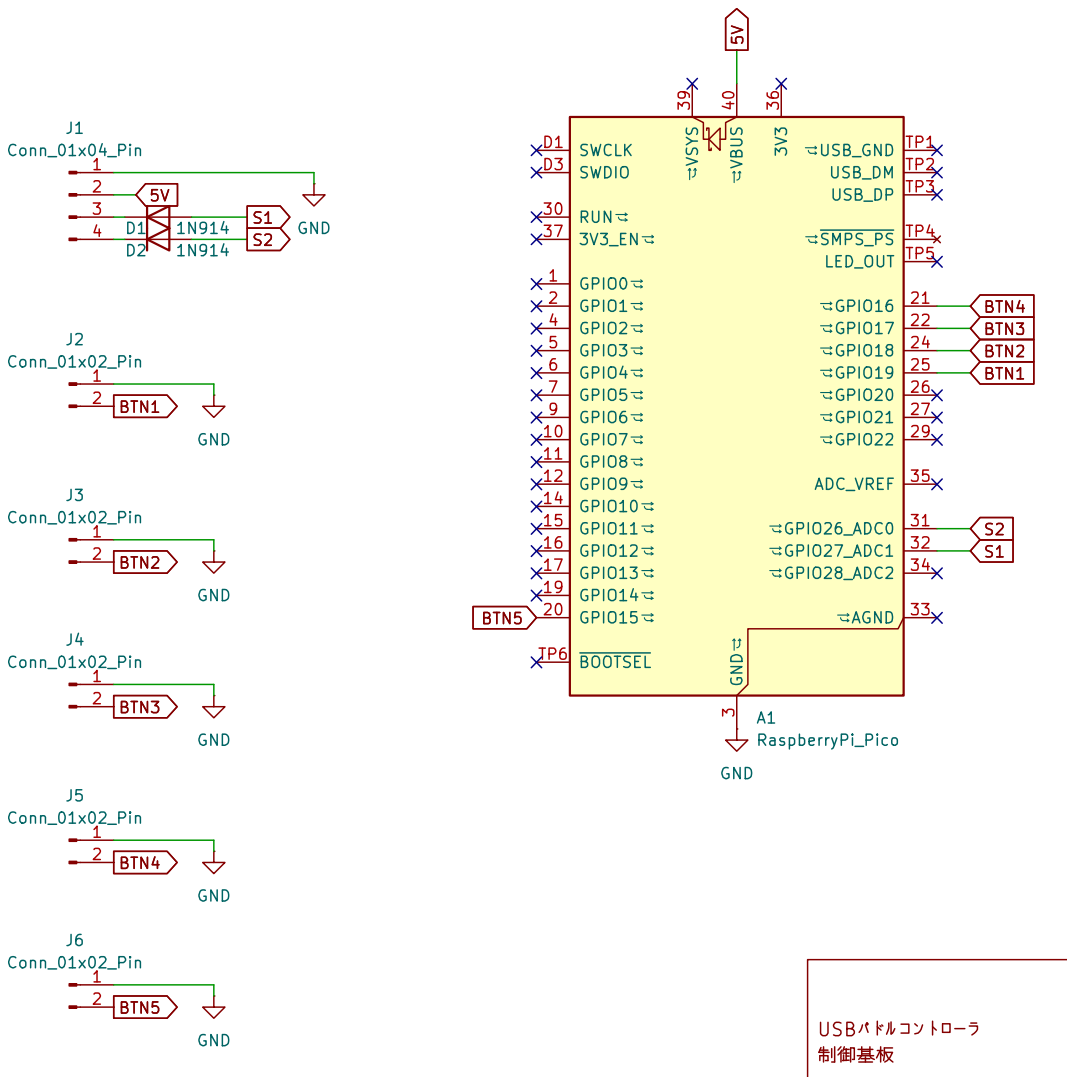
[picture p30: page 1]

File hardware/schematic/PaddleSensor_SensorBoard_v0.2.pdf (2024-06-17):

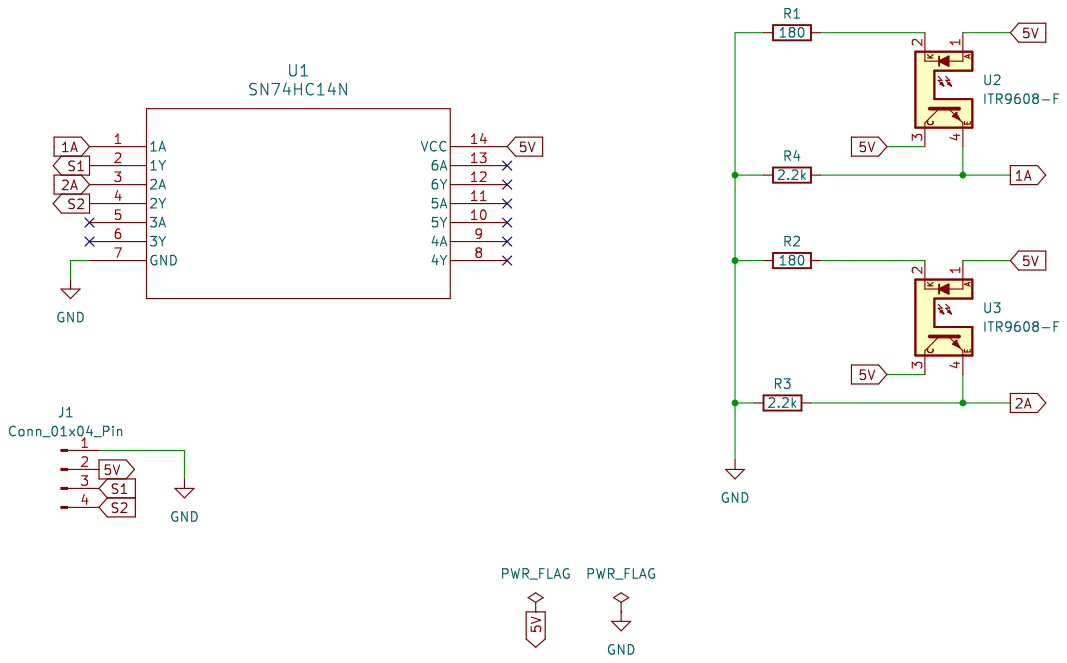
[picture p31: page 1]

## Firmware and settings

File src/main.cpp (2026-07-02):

#include <Arduino.h>
#include <hardware/gpio.h>
#include <hardware/pio.h>
#include <hardware/watchdog.h>
#include <pico/multicore.h>
#include <pico/critical_section.h>
#include <SPI.h>
#include <EEPROM.h>
#include <Adafruit_TinyUSB.h>
#if defined(BOARD_RP2040_ZERO)
#include <Adafruit_NeoPixel.h>
#endif
#include <define.hpp>
#include "s1s2_encoder.pio.h"

uint8_t const desc_hid_report_mouse[] =
{
    MY_TUD_HID_REPORT_DESC_MOUSE()
};
uint8_t const desc_hid_report_gamepad[] =
{
  MY_TUD_HID_REPORT_DESC_GAMEPAD()
};

enum DeviceMode : uint8_t {
  DEVICE_MODE_MOUSE = 0,
  DEVICE_MODE_GAMEPAD,
  DEVICE_MODE_MAX
};

Adafruit_USBD_HID usb_hid;
my_hid_mouse_report_t   mouse_report;
joykey_hid_gamepad_report_t gamepad_report;

bool axisAlt = false;
DeviceMode currentMode = DEVICE_MODE_MOUSE;

uint8_t speedIndexByMode[DEVICE_MODE_MAX] = {0};
uint8_t autoFireFlagsByMode[DEVICE_MODE_MAX] = {0};

uint8_t lastBtn1Sts;
uint8_t btn1Sts;
uint8_t lastBtn2Sts;
uint8_t btn2Sts;
uint8_t lastBtn3Sts;
uint8_t btn3Sts;
uint8_t lastBtnAxisSts;
uint8_t btnAxisSts;
uint8_t lastBtnSpdSts;
uint8_t btnSpdSts;
bool speedComboActive = false;
bool speedComboConsumed = false;
bool modeSwitchComboActive = false;

bool btn1AutoFire = false;
bool btn2AutoFire = false;
bool btn3AutoFire = false;
bool autoFireStateBtn1 = false;
bool autoFireStateBtn2 = false;
bool autoFireStateBtn3 = false;
unsigned long lastAutoFireBtn1 = 0;
unsigned long lastAutoFireBtn2 = 0;
unsigned long lastAutoFireBtn3 = 0;

unsigned long lastTimeBtn1 = micros();
unsigned long lastTimeBtn2 = micros();
unsigned long lastTimeBtn3 = micros();
unsigned long lastTimeBtnAxis = micros();
unsigned long lastTimeBtnSpd = micros();

int16_t cnt;
int16_t mouseStepIdx = 0;
int16_t mouseStep = mouseStepTable[mouseStepIdx];

PIO s1s2Pio = pio1;
uint s1s2Sm = 0;
uint s1s2ProgramOffset = 0;
uint8_t s1s2LastSts = 0;

critical_section_t reportStateCs;
critical_section_t settingsSaveCs;
critical_section_t modeSwitchCs;
critical_section_t modeStateCs;
critical_section_t ledBlinkCs;
critical_section_t speedBlinkCs;
volatile uint8_t sharedButtons = 0;
volatile bool sharedAxisAlt = false;
volatile bool settingsSaveRequested = false;
volatile bool modeSwitchRequested = false;
volatile uint8_t sharedMode = DEVICE_MODE_MOUSE;
volatile bool activityLedBlinkRequested = false;
volatile uint8_t speedLedBlinkRequestedCount = 0;

bool startupLedActive = false;
uint8_t startupLedMode = DEVICE_MODE_MOUSE;
unsigned long startupLedStartMs = 0;
bool startupLedLastOn = false;
bool activityLedBlinkActive = false;
unsigned long activityLedBlinkUntilMs = 0;
unsigned long activityLedNextAllowedMs = 0;
bool speedLedBlinkActive = false;
bool speedLedBlinkOn = false;
uint8_t speedLedBlinkRemaining = 0;
unsigned long speedLedBlinkNextToggleMs = 0;

#if defined(BOARD_RP2040_ZERO)
Adafruit_NeoPixel statusLed(1, PIN_LED, NEO_GRB + NEO_KHZ800);
#endif

struct DeviceSettings {
  uint8_t magic;
  uint8_t version;
  uint8_t currentMode;
  uint8_t speedIndexByMode[DEVICE_MODE_MAX];
  uint8_t autoFireFlagsByMode[DEVICE_MODE_MAX];
  uint8_t mode;
  uint8_t reserved;
  uint8_t checksum;
};

static uint8_t const featureReport[8] = {0x21, 0x26, 0x02, 0x04, 0x00, 0x00, 0x00, 0x00};
static uint8_t lastOutputReport[8] = {0};

uint16_t hidPadGetReportCallback(uint8_t report_id, hid_report_type_t report_type, uint8_t *buffer, uint16_t reqlen)
{
  (void)report_id;

  if (report_type == HID_REPORT_TYPE_FEATURE)
  {
    uint16_t len = (reqlen < sizeof(featureReport)) ? reqlen : (uint16_t)sizeof(featureReport);
    memcpy(buffer, featureReport, len);
    return len;
  }

  return 0;
}

void hidPadSetReportCallback(uint8_t report_id, hid_report_type_t report_type, uint8_t const *buffer, uint16_t bufsize)
{
  (void)report_id;

  if ((report_type == HID_REPORT_TYPE_OUTPUT || report_type == HID_REPORT_TYPE_FEATURE) && bufsize)
  {
    uint16_t len = (bufsize < sizeof(lastOutputReport)) ? bufsize : (uint16_t)sizeof(lastOutputReport);
    memcpy(lastOutputReport, buffer, len);
  }
}

uint8_t calcSettingsChecksum(const DeviceSettings& settings) {
  uint8_t checksum = settings.magic ^ settings.version ^ settings.currentMode ^ settings.mode ^ settings.reserved;
  for (uint8_t i = 0; i < DEVICE_MODE_MAX; ++i) {
    checksum ^= settings.speedIndexByMode[i];
    checksum ^= settings.autoFireFlagsByMode[i];
  }
  return checksum;
}

uint8_t getRuntimeAutoFireFlags() {
  return (uint8_t)((btn1AutoFire ? 0x01 : 0x00) |
                   (btn2AutoFire ? 0x02 : 0x00) |
                   (btn3AutoFire ? 0x04 : 0x00));
}

void applyRuntimeAutoFireFlags(uint8_t flags) {
  btn1AutoFire = (flags & 0x01) != 0;
  btn2AutoFire = (flags & 0x02) != 0;
  btn3AutoFire = (flags & 0x04) != 0;
}

void syncRuntimeSettingsToModeCache(DeviceMode mode) {
  if (mode >= DEVICE_MODE_MAX) {
    return;
  }

  uint8_t speedIndex = (mouseStepIdx >= 0) ? (uint8_t)mouseStepIdx : 0;
  if (speedIndex >= sizeof(mouseStepTable)) {
    speedIndex = 0;
  }

  speedIndexByMode[mode] = speedIndex;
  autoFireFlagsByMode[mode] = getRuntimeAutoFireFlags();
}

void applyModeCacheToRuntimeSettings(DeviceMode mode) {
  if (mode >= DEVICE_MODE_MAX) {
    return;
  }

  uint8_t speedIndex = speedIndexByMode[mode];
  if (speedIndex >= sizeof(mouseStepTable)) {
    speedIndex = 0;
  }

  mouseStepIdx = speedIndex;
  mouseStep = (currentMode == DEVICE_MODE_MOUSE) ? mouseStepTable[mouseStepIdx] : mouseStepTable[0] * 4;
  applyRuntimeAutoFireFlags(autoFireFlagsByMode[mode]);
}

void saveSettingsToNand() {
  syncRuntimeSettingsToModeCache(currentMode);

  DeviceSettings settings = {
    SETTINGS_MAGIC,
    SETTINGS_VERSION,
    (uint8_t)currentMode,
    {0},
    {0},
    (uint8_t)currentMode,
    0,
    0
  };
  for (uint8_t i = 0; i < DEVICE_MODE_MAX; ++i) {
    settings.speedIndexByMode[i] = speedIndexByMode[i];
    settings.autoFireFlagsByMode[i] = autoFireFlagsByMode[i];
  }
  settings.checksum = calcSettingsChecksum(settings);

  // RP2040はフラッシュ書き込み中に他コア実行が干渉すると停止することがあるため、
  // 保存中だけもう一方のコアをロックアウトする。
  multicore_lockout_start_blocking();
  EEPROM.put(0, settings);
  EEPROM.commit();
  multicore_lockout_end_blocking();
}

void requestSettingsSave() {
  critical_section_enter_blocking(&settingsSaveCs);
  settingsSaveRequested = true;
  critical_section_exit(&settingsSaveCs);
}

bool consumeSettingsSaveRequest() {
  bool requested;
  critical_section_enter_blocking(&settingsSaveCs);
  requested = settingsSaveRequested;
  settingsSaveRequested = false;
  critical_section_exit(&settingsSaveCs);
  return requested;
}

void requestModeSwitch() {
  critical_section_enter_blocking(&modeSwitchCs);
  modeSwitchRequested = true;
  critical_section_exit(&modeSwitchCs);
}

void requestActivityLedBlink() {
  critical_section_enter_blocking(&ledBlinkCs);
  activityLedBlinkRequested = true;
  critical_section_exit(&ledBlinkCs);
}

void requestSpeedLedBlink(uint8_t count) {
  critical_section_enter_blocking(&speedBlinkCs);
  speedLedBlinkRequestedCount = count;
  critical_section_exit(&speedBlinkCs);
}

bool consumeActivityLedBlinkRequest() {
  bool requested;
  critical_section_enter_blocking(&ledBlinkCs);
  requested = activityLedBlinkRequested;
  activityLedBlinkRequested = false;
  critical_section_exit(&ledBlinkCs);
  return requested;
}

uint8_t consumeSpeedLedBlinkRequest() {
  uint8_t count;
  critical_section_enter_blocking(&speedBlinkCs);
  count = speedLedBlinkRequestedCount;
  speedLedBlinkRequestedCount = 0;
  critical_section_exit(&speedBlinkCs);
  return count;
}

bool consumeModeSwitchRequest() {
  bool requested;
  critical_section_enter_blocking(&modeSwitchCs);
  requested = modeSwitchRequested;
  modeSwitchRequested = false;
  critical_section_exit(&modeSwitchCs);
  return requested;
}

void startupLedSet(bool on, DeviceMode mode) {
#if defined(BOARD_RP2040_ZERO)
  statusLed.setBrightness(STARTUP_LED_BRIGHTNESS);
  if (on) {
    if (mode == DEVICE_MODE_GAMEPAD) {
      statusLed.setPixelColor(0, statusLed.Color(0, 255, 0));
    } else {
      statusLed.setPixelColor(0, statusLed.Color(255, 128, 0));
    }
  } else {
    statusLed.setPixelColor(0, statusLed.Color(0, 0, 0));
  }
  statusLed.show();
#else
  digitalWrite(PIN_LED, on ? HIGH : LOW);
#endif
}

void activityLedSet(bool on) {
#if defined(BOARD_RP2040_ZERO)
  statusLed.setBrightness(ACTIVITY_LED_BRIGHTNESS);
  if (on) {
    statusLed.setPixelColor(0, statusLed.Color(255, 255, 0));
  } else {
    statusLed.setPixelColor(0, statusLed.Color(0, 0, 0));
  }
  statusLed.show();
#else
  digitalWrite(PIN_LED, on ? HIGH : LOW);
#endif
}

void speedLedSet(bool on) {
#if defined(BOARD_RP2040_ZERO)
  statusLed.setBrightness(ACTIVITY_LED_BRIGHTNESS);
  if (on) {
    statusLed.setPixelColor(0, statusLed.Color(128, 200, 255));
  } else {
    statusLed.setPixelColor(0, statusLed.Color(0, 0, 0));
  }
  statusLed.show();
#else
  digitalWrite(PIN_LED, on ? HIGH : LOW);
#endif
}

void restoreLedBaseState() {
  if (activityLedBlinkActive) {
    activityLedSet(true);
    return;
  }

  bool startupOn = startupLedActive && startupLedLastOn;
  if (startupOn) {
    startupLedSet(true, (DeviceMode)startupLedMode);
  } else {
    startupLedSet(false, (DeviceMode)startupLedMode);
  }
}

void startStartupLedPattern(DeviceMode mode) {
  startupLedMode = (uint8_t)mode;
  startupLedStartMs = millis();
  startupLedActive = true;
  startupLedLastOn = true;
  startupLedSet(true, mode);
}

void updateStartupLedPattern(unsigned long nowMs) {
  if (!startupLedActive) {
    return;
  }

  unsigned long elapsedMs = nowMs - startupLedStartMs;
  if (elapsedMs >= STARTUP_LED_TOTAL_MS) {
    if (startupLedLastOn) {
      if (!activityLedBlinkActive) {
        startupLedSet(false, (DeviceMode)startupLedMode);
      }
      startupLedLastOn = false;
    }
    startupLedActive = false;
    return;
  }

  bool nextOn = true;
  if (startupLedMode == DEVICE_MODE_GAMEPAD) {
    nextOn = ((elapsedMs / STARTUP_LED_BLINK_HALF_MS) % 2u) == 0u;
  }

  if (nextOn != startupLedLastOn) {
    if (!activityLedBlinkActive) {
      startupLedSet(nextOn, (DeviceMode)startupLedMode);
    }
    startupLedLastOn = nextOn;
  }
}

void updateActivityLedBlink(unsigned long nowMs) {
  if (consumeActivityLedBlinkRequest()) {
    if ((long)(nowMs - activityLedNextAllowedMs) >= 0) {
      activityLedBlinkActive = true;
      activityLedBlinkUntilMs = nowMs + ACTIVITY_LED_ON_MS;
      activityLedNextAllowedMs = nowMs + ACTIVITY_LED_ON_MS + ACTIVITY_LED_OFF_MS;
      activityLedSet(true);
    }
  }

  if (activityLedBlinkActive && (long)(nowMs - activityLedBlinkUntilMs) >= 0) {
    activityLedBlinkActive = false;

    if (!speedLedBlinkActive) {
      restoreLedBaseState();
    }
  }
}

void updateSpeedLedBlink(unsigned long nowMs) {
  uint8_t requestedCount = consumeSpeedLedBlinkRequest();
  if (requestedCount > 0) {
    speedLedBlinkActive = true;
    speedLedBlinkRemaining = requestedCount;
    speedLedBlinkOn = true;
    speedLedBlinkNextToggleMs = nowMs + SPEED_LED_ON_MS;
    speedLedSet(true);
  }

  if (!speedLedBlinkActive) {
    return;
  }

  if ((long)(nowMs - speedLedBlinkNextToggleMs) < 0) {
    return;
  }

  if (speedLedBlinkOn) {
    speedLedSet(false);
    speedLedBlinkOn = false;
    if (speedLedBlinkRemaining > 0) {
      --speedLedBlinkRemaining;
    }

    if (speedLedBlinkRemaining == 0) {
      speedLedBlinkActive = false;
      restoreLedBaseState();
      return;
    }

    speedLedBlinkNextToggleMs = nowMs + SPEED_LED_OFF_MS;
    return;
  }

  speedLedSet(true);
  speedLedBlinkOn = true;
  speedLedBlinkNextToggleMs = nowMs + SPEED_LED_ON_MS;
}

void loadSettingsFromNand() {
  DeviceSettings settings;
  EEPROM.get(0, settings);

  if (settings.magic != SETTINGS_MAGIC ||
      settings.version != SETTINGS_VERSION ||
      settings.checksum != calcSettingsChecksum(settings)) {
    speedIndexByMode[DEVICE_MODE_MOUSE] = 0;
    speedIndexByMode[DEVICE_MODE_GAMEPAD] = 0;
    autoFireFlagsByMode[DEVICE_MODE_MOUSE] = 0;
    autoFireFlagsByMode[DEVICE_MODE_GAMEPAD] = 0;
    applyModeCacheToRuntimeSettings(currentMode);
    return;
  }

  for (uint8_t i = 0; i < DEVICE_MODE_MAX; ++i) {
    speedIndexByMode[i] = settings.speedIndexByMode[i];
    autoFireFlagsByMode[i] = settings.autoFireFlagsByMode[i];
  }

  if (settings.currentMode < DEVICE_MODE_MAX) {
    currentMode = (DeviceMode)settings.currentMode;
  } else if (settings.mode < DEVICE_MODE_MAX) {
    // 互換性: 旧フィールドが有効ならそれを使う。
    currentMode = (DeviceMode)settings.mode;
  }

  applyModeCacheToRuntimeSettings(currentMode);
}

int8_t toMouseDelta(int16_t value) {
  if (value > 127) {
    return (int8_t)127;
  }
  if (value < -127) {
    return (int8_t)-127;
  }
  return (int8_t)value;
}

uint32_t mapMouseButtonsToGamepadButtons(uint8_t mouseButtons) {
  uint16_t gamepadButtons = 0;
  static uint8_t PpShift = OUT_PAD_SQUARE;
  static bool LastPpShiftTrig = false;
  static bool wasR2Pressed = false;
  static unsigned long r2PressStartUs = 0;
  static bool l2BurstActive = false;
  static unsigned long l2BurstStartUs = 0;
  static unsigned long lastL2PulseUs = 0;
  static bool l2PulseActive = false;
  static unsigned long l2PulseStartUs = 0;
  unsigned long now = micros();

  // micros() がオーバーフローした場合に備えて開始時刻を補正する。
  if (r2PressStartUs > now) {
    r2PressStartUs = now;
  }
  if (l2BurstStartUs > now) {
    l2BurstStartUs = now;
  }
  if (lastL2PulseUs > now) {
    lastL2PulseUs = now;
  }
  if (l2PulseStartUs > now) {
    l2PulseStartUs = now;
  }

  if ((mouseButtons & 0x01) != 0) {
    gamepadButtons |= OUT_PAD_R2;
  }
  if ((mouseButtons & 0x02) != 0) {
    if (!LastPpShiftTrig) {
      PpShift = (PpShift == OUT_PAD_SQUARE) ? OUT_PAD_CROSS : OUT_PAD_SQUARE;
    }
    LastPpShiftTrig = true;
    gamepadButtons |= PpShift;
  } else {
    LastPpShiftTrig = false;
  }
  if ((mouseButtons & 0x04) != 0) {
    gamepadButtons |= OUT_PAD_TRIANGLE;
  }
  if ((mouseButtons & 0x08) != 0) {
    gamepadButtons |= OUT_PAD_PS;
  }

  bool r2Pressed = (gamepadButtons & OUT_PAD_R2) != 0;
  if (r2Pressed) {
    if (!wasR2Pressed) {
      r2PressStartUs = now;
    }
    wasR2Pressed = true;
    l2BurstActive = false;
    l2PulseActive = false;
  } else {
    if (wasR2Pressed) {
      unsigned long heldUs = now - r2PressStartUs;
      if (heldUs >= GAMEPAD_R2_HOLD_TRIGGER_US) {
        l2BurstActive = true;
        l2BurstStartUs = now;
        lastL2PulseUs = now - GAMEPAD_L2_PULSE_INTERVAL_US;
        l2PulseActive = false;
      }
    }
    wasR2Pressed = false;
  }

  if (l2BurstActive) {
    unsigned long elapsedUs = now - l2BurstStartUs;
    if (elapsedUs < GAMEPAD_L2_BURST_DURATION_US) {
      if (!l2PulseActive && (now - lastL2PulseUs) >= GAMEPAD_L2_PULSE_INTERVAL_US) {
        l2PulseActive = true;
        l2PulseStartUs = now;
        lastL2PulseUs = now;
        requestActivityLedBlink();
      }

      if (l2PulseActive && (now - l2PulseStartUs) < GAMEPAD_L2_PULSE_WIDTH_US) {
        gamepadButtons |= OUT_PAD_L2;
      } else {
        l2PulseActive = false;
      }
    } else {
      l2BurstActive = false;
      l2PulseActive = false;
    }
  }

  return gamepadButtons;
}

void publishReportState(uint8_t buttons, bool axisIsAlt) {
  critical_section_enter_blocking(&reportStateCs);
  sharedButtons = buttons;
  sharedAxisAlt = axisIsAlt;
  critical_section_exit(&reportStateCs);
}

void publishModeState(DeviceMode mode) {
  critical_section_enter_blocking(&modeStateCs);
  sharedMode = (uint8_t)mode;
  critical_section_exit(&modeStateCs);
}

DeviceMode consumeModeState() {
  uint8_t mode;
  critical_section_enter_blocking(&modeStateCs);
  mode = sharedMode;
  critical_section_exit(&modeStateCs);

  if (mode >= DEVICE_MODE_MAX) {
    return DEVICE_MODE_MOUSE;
  }
  return (DeviceMode)mode;
}

void initS1S2Pio() {
  s1s2ProgramOffset = pio_add_program(s1s2Pio, &s1s2_encoder_program);
  pio_sm_config config = s1s2_encoder_program_get_default_config(s1s2ProgramOffset);
  sm_config_set_in_pins(&config, PIN_S2);
  sm_config_set_in_shift(&config, false, false, 32);

  pio_gpio_init(s1s2Pio, PIN_S2);
  pio_gpio_init(s1s2Pio, PIN_S1);
  gpio_pull_up(PIN_S2);
  gpio_pull_up(PIN_S1);
  pio_sm_set_consecutive_pindirs(s1s2Pio, s1s2Sm, PIN_S2, 2, false);

  pio_sm_init(s1s2Pio, s1s2Sm, s1s2ProgramOffset, &config);
  pio_sm_set_enabled(s1s2Pio, s1s2Sm, true);

  s1s2LastSts = (gpio_get(PIN_S1) << 1) | gpio_get(PIN_S2);
}

void consumeS1S2Pio() {
  static const int8_t transitionTable[16] = {
    0, -1, 1, 0,
    1, 0, 0, -1,
    -1, 0, 0, 1,
    0, 1, -1, 0,
  };

  // RX FIFOが埋まり続けるとloop全体が飢餓するため、
  // 1回の呼び出しで処理するサンプル数に上限を設ける。
  const uint8_t maxSamplesPerLoop = 64;
  uint8_t samples = 0;

  while (!pio_sm_is_rx_fifo_empty(s1s2Pio, s1s2Sm) && samples < maxSamplesPerLoop) {
    uint8_t newSts = (uint8_t)(pio_sm_get(s1s2Pio, s1s2Sm) & 0x03);
    uint8_t transition = (uint8_t)((s1s2LastSts << 2) | newSts);
    int8_t delta = transitionTable[transition];

    if (delta != 0) {
      cnt += delta;
    }
    s1s2LastSts = newSts;
    ++samples;
  }
}
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
void loop() {
  static unsigned long nextReportUs = 0;
  static bool reportPending = false;
  static bool hasLastSentReport = false;
  static int8_t lastSentStepValue = 0;
  static uint8_t lastSentButtons = 0;
  static bool lastSentAxisAlt = false;
  static int16_t lastGamepadCnt = 0;
  static float gamepadAccumulatedCnt = 0.0f;
  unsigned long now = micros();
  unsigned long nowMs = millis();

  updateStartupLedPattern(nowMs);
  updateActivityLedBlink(nowMs);
  updateSpeedLedBlink(nowMs);

  if (nextReportUs == 0) {
    nextReportUs = now + REPORT_INTERVAL_US;
  }

  if (consumeSettingsSaveRequest()) {
    saveSettingsToNand();
  }

  if (consumeModeSwitchRequest()) {
    syncRuntimeSettingsToModeCache(currentMode);
    currentMode = (currentMode == DEVICE_MODE_MOUSE) ? DEVICE_MODE_GAMEPAD : DEVICE_MODE_MOUSE;
    applyModeCacheToRuntimeSettings(currentMode);
    publishModeState(currentMode);
    axisAlt = false;
    publishReportState(0, false);
    saveSettingsToNand();
    // ホスト側で古いHID構成が残るのを避けるため、切替時はいったん明示的に切断する。
    TinyUSBDevice.detach();
    delay(250);
    watchdog_reboot(0, 0, 10);
    while (true) {
      tight_loop_contents();
    }
  }

  if ((long)(now - nextReportUs) >= 0) {
    do {
      nextReportUs += REPORT_INTERVAL_US;
    } while ((long)(now - nextReportUs) >= 0);
    reportPending = true;
  }

  consumeS1S2Pio();

  int16_t pendingCnt;
  noInterrupts();
  pendingCnt = cnt;
  interrupts();

  int8_t stepValue;
  if (currentMode == DEVICE_MODE_GAMEPAD) {
    if (pendingCnt != 0) {
      int16_t cntAbs = abs(pendingCnt);
      int16_t t = GAMEPAD_MAGNIFIER_THRESHOLD - cntAbs > GAMEPAD_MAGNIFIER_THRESHOLD ? GAMEPAD_MAGNIFIER_THRESHOLD : cntAbs;
      float magnification = 1.0f + (float)(GAMEPAD_MAGNIFIER_MAX * t * t) / (float)(GAMEPAD_MAGNIFIER_THRESHOLD * GAMEPAD_MAGNIFIER_THRESHOLD);
      gamepadAccumulatedCnt = gamepadAccumulatedCnt + ((float)pendingCnt * magnification);
    } else {
      gamepadAccumulatedCnt = gamepadAccumulatedCnt * 0.3f;
    }
    stepValue = toMouseDelta((int16_t)gamepadAccumulatedCnt);
    gamepadAccumulatedCnt = (float)(abs(stepValue) > 110 ? stepValue * 0.8f : stepValue);
  } else {
    int16_t scaledCnt = pendingCnt * mouseStep;
    stepValue = toMouseDelta(scaledCnt);
  }

  uint8_t reportButtons;
  bool reportAxisAlt;
  critical_section_enter_blocking(&reportStateCs);
  reportButtons = sharedButtons;
  reportAxisAlt = sharedAxisAlt;
  critical_section_exit(&reportStateCs);

  mouse_report.buttons = reportButtons & 0x07;

  if (currentMode == DEVICE_MODE_MOUSE) {
    if (reportAxisAlt) {
      mouse_report.x = 0;
      mouse_report.y = stepValue;
    } else {
      mouse_report.x = stepValue;
      mouse_report.y = 0;
    }
  } else {
    gamepad_report.x = reportAxisAlt ? 127 : stepValue + 127;
    gamepad_report.y = reportAxisAlt ? stepValue + 127 : 127;
    gamepad_report.z = 127;
    gamepad_report.rz = 127;
    gamepad_report.hat = GAMEPAD_HAT_CENTER;
    gamepad_report.buttons = mapMouseButtonsToGamepadButtons(reportButtons);
    memset(gamepad_report.vendorInput, 0, sizeof(gamepad_report.vendorInput));
    memset(gamepad_report.analog, 0, sizeof(gamepad_report.analog));
  }

  bool reportChanged = !hasLastSentReport ||
                       (currentMode == DEVICE_MODE_GAMEPAD) ||
                       (stepValue != lastSentStepValue) ||
                       (reportButtons != lastSentButtons) ||
                       (reportAxisAlt != lastSentAxisAlt);

  if (reportChanged) {
    reportPending = true;
  }

  if (!reportPending) {
    return;
  }

  if (TinyUSBDevice.mounted() && usb_hid.ready()) {
    if (currentMode == DEVICE_MODE_MOUSE) {
      usb_hid.sendReport(0, &mouse_report, sizeof(mouse_report));
    } else {
      usb_hid.sendReport(0, &gamepad_report, sizeof(gamepad_report));
    }

    noInterrupts();
    cnt -= pendingCnt;
    interrupts();

    hasLastSentReport = true;
    lastSentStepValue = stepValue;
    lastSentButtons = reportButtons;
    lastSentAxisAlt = reportAxisAlt;
    nextReportUs = now + REPORT_INTERVAL_US;
    reportPending = false;
  }
}

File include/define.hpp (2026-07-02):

#pragma once

#include <Arduino.h>

#ifdef BOARD_PICO
  #define PIN_S1      D27
  #define PIN_S2      D26

  #define PIN_BTN1    D19
  #define PIN_BTN2    D18
  #define PIN_BTN3    D15
  #define PIN_BTNSPD  D17
  #define PIN_BTNAXIS D16

  #ifndef PIN_LED
    #define PIN_LED   D25
  #endif
#endif

#ifdef BOARD_RP2040_ZERO
  #define PIN_S1      D27
  #define PIN_S2      D26

  #define PIN_BTN1    D13
  #define PIN_BTN2    D12
  #define PIN_BTN3    D11
  #define PIN_BTNSPD  D10
  #define PIN_BTNAXIS D9

  #ifdef PIN_LED
    #undef PIN_LED
  #endif
  #define PIN_LED     D16
#endif

#define DIR_N       (0u)
#define DIR_RIGHT   (1u)
#define DIR_LEFT    (2u)

#define INTERVAL      (1000u)
#define INTERVAL_BTN  (10000u)

#define OUT_PAD_SQUARE (1u << 0)
#define OUT_PAD_CROSS (1u << 1)
#define OUT_PAD_CIRCLE (1u << 2)
#define OUT_PAD_TRIANGLE (1u << 3)
#define OUT_PAD_L2 (1u << 6)
#define OUT_PAD_R2 (1u << 7)
#define OUT_PAD_PS (1u << 12)

typedef struct
{
  uint16_t vid;
  uint16_t pid;
  const char *manufacturer;
  const char *product;
} UsbIdentityProfile;

// USB VID/PID profile IDs used by keyAssign[].usbProfile.
enum
{
  USB_ID_PROFILE_MOUSE = 0,
  USB_ID_PROFILE_GAMEPAD,
  USB_ID_PROFILE_MAX
};

// USB identity table indexed by USB_ID_PROFILE_*.
const UsbIdentityProfile usbIdentityProfiles[USB_ID_PROFILE_MAX] = {
    {0x2E8A, 0x0005, "USB PADDLE CONTROLLER", "PADDLE"},
    {0x2E8A, 0x0004, "USB PADDLE CONTROLLER", "POLE POSITION PADDLE"},
};

#define MY_TUD_HID_REPORT_DESC_GAMEPAD(...)                           \
    HID_USAGE_PAGE(HID_USAGE_PAGE_DESKTOP),                                 \
    HID_USAGE(HID_USAGE_DESKTOP_GAMEPAD),                               \
    HID_COLLECTION(HID_COLLECTION_APPLICATION), /* Report ID if any */  \
      __VA_ARGS__                                                         \
          HID_LOGICAL_MIN(0),                                             \
      HID_LOGICAL_MAX(1),                                                 \
      HID_PHYSICAL_MIN(0),                                                \
      HID_PHYSICAL_MAX(1),                                                \
      HID_REPORT_SIZE(1),                                                 \
      HID_REPORT_COUNT(13),                                               \
      HID_USAGE_PAGE(HID_USAGE_PAGE_BUTTON),                              \
      HID_USAGE_MIN(1),                                                   \
      HID_USAGE_MAX(13),                                                  \
      HID_INPUT(HID_DATA | HID_VARIABLE | HID_ABSOLUTE),                  \
      HID_REPORT_COUNT(3),                                                \
      HID_INPUT(HID_CONSTANT | HID_ARRAY | HID_ABSOLUTE),                 \
      HID_USAGE_PAGE(HID_USAGE_PAGE_DESKTOP),                             \
      HID_LOGICAL_MAX(7),                                                 \
      HID_PHYSICAL_MAX_N(315, 2),                                         \
      HID_REPORT_SIZE(4),                                                 \
      HID_REPORT_COUNT(1),                                                \
      HID_UNIT(0x14),                                                     \
      HID_USAGE(HID_USAGE_DESKTOP_HAT_SWITCH),                            \
      HID_INPUT(HID_DATA | HID_VARIABLE | HID_ABSOLUTE | HID_NULL_STATE), \
      HID_UNIT(0),                                                        \
      HID_REPORT_COUNT(1),                                                \
      HID_INPUT(HID_CONSTANT | HID_ARRAY | HID_ABSOLUTE),                 \
      HID_LOGICAL_MAX_N(0xff, 2),                                         \
      HID_PHYSICAL_MAX_N(0xff, 2),                                        \
      HID_USAGE(HID_USAGE_DESKTOP_X),                                     \
      HID_USAGE(HID_USAGE_DESKTOP_Y),                                     \
      HID_USAGE(HID_USAGE_DESKTOP_Z),                                     \
      HID_USAGE(HID_USAGE_DESKTOP_RZ),                                    \
      HID_REPORT_SIZE(8),                                                 \
      HID_REPORT_COUNT(4),                                                \
      HID_INPUT(HID_DATA | HID_VARIABLE | HID_ABSOLUTE),                  \
      HID_USAGE_PAGE_N(0xFF00, 2),                                        \
      HID_USAGE(0x20),                                                    \
      HID_USAGE(0x21),                                                    \
      HID_USAGE(0x22),                                                    \
      HID_USAGE(0x23),                                                    \
      HID_USAGE(0x24),                                                    \
      HID_USAGE(0x25),                                                    \
      HID_USAGE(0x26),                                                    \
      HID_USAGE(0x27),                                                    \
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

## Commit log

2024-06-18 ケースのstlファイル追加
    [PaddleCase_BOTTOM.stl, PaddleCase_TOP.stl]
2024-06-24 ケースstl更新
    [PaddleCase_BOTTOM.stl, PaddleCase_TOP.stl]
2025-05-30 低速モード追加
2025-05-30 ファーム更新
2025-06-01 大型ケース追加
    [PaddleCaseLarge.3mf, PaddleCaseLarge_BOTTOM.stl, PaddleCaseLarge_TOP.stl]
2025-06-01 READMEに使用部品追記
2025-07-08 ボタン追加
    [PaddleCaseLarge_4BTN.3mf, PaddleCaseLarge_TOP_4BTN.stl]
2026-05-06 パドルの回転量をなめらかに
2026-05-06 起動時の移動量変更修正
2026-05-07 センターボタン処理を追加
2026-05-07 README修正
2026-05-07 筐体画像差し替え
2026-05-07 筐体内部画像差し替え
2026-05-07 センタースイッチ（物理）対応
2026-05-07 回転初期のダルを解消
2026-05-07 README更新
2026-05-14 連射モード追加 X/Y軸切替を押しながら左右のセンターボタン削除 README更新
    [PaddleCaseLarge.3mf, PaddleCaseLarge_4BTN.3mf, PaddleCaseLarge_BOTTOM.stl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]
2026-05-14 README更新 中速の速度調整
2026-05-15 スピード切り替えを4段階に変更
2026-05-15 USB送信処理を分離 平滑化処理を削除 パドル切り戻し時の動作を改善
2026-05-15 変化なしで送信スキップした場合、インターバルを置かずに次の変化があったタイミングで送信するよう修正
2026-05-19 パドル移動のカクつき改善
2026-05-21 パドル速度、連射速度の設定を保存できるようにした
2026-06-06 回転の読み出し方法を改善
2026-06-18 GAMEPADモード追加
2026-06-18 パッドモード時に速度切替ボタンをPSボタン化
2026-06-21 ゲームパッドモードにオートブレーキ追加
2026-07-02 RP2040-Zero対応
2026-07-02 RP2040-Zero用ガーバーファイル名修正
2026-07-02 RP2040-Zero用ケース追加
